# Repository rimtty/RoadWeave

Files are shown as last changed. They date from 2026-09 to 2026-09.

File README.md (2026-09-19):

# RoadWeave

RoadWeave は、インターネットや携帯回線がない場所でも、ツーリング中の車両どうしでグループ音声と位置情報を共有する小型端末の研究開発プロジェクトです。

製品の核は **ESP32-S3 + Wi-Fi HaLow + IP-PTT** です。最初は2台のブレッドボードで低遅延の半二重音声を成立させ、そこから「オフラインのDiscord風ボイスルーム」、指定相手へのPTT、個別ミュート・音量、音声記録、GPS隊列表示へ段階的に育てます。

## 開発ライン

| ライン | 無線モジュール | 位置づけ |
|---|---|---|
| P0 reference | Seeed Studio Wio-WM6180 / FGH100M-H / MM6108 | XIAO ESP32S3へ直接挿し、公式board profileでhost/networkを先行検証する。量産BOMの決定ではない |
| Main | Heltec HT-HC01 V2 / MM6108 / 27 dBm級 | 機能・距離・電力の主開発。日本国内では適合確認前に通常の空中線送信を行わず、シールド環境・導通試験または適法な地域で評価する |
| Japan side line | FGH100M-J / MegaChips MRF61_A | 日本向け製品化を並走検討。認証、antenna、国内band、出力、Duty、供給条件を実機・一次資料で検証する |

最初にWM6180を使うのは、はんだ付けや自作carrierなしで、公式pin/BCF設定からsoftwareを検証できるためです。WM6180での成功はHC01 V2固有の電源・PA・RF性能を証明しません。HC01 V2を主系にするのは、PA/LNAを含むRF性能と入手性を評価するためで、日本で販売・使用する製品がHC01 V2のまま成立する、という意味ではありません。

## 最初の成功条件

2台のブレッドボードで次を再現できたら P0 完了です。

1. Node AでPTTを押す
2. 16 kHz mono音声をIMA-ADPCM化してUDP送信する
3. Node Bのスピーカーから100〜150 ms以内を目標に再生する
4. パケット損失、遅延、消費電力、RF airtimeを記録する

LCD、GPS、Opus、録音、メッシュはP0の完了条件に含めません。

## リポジトリ構成

```text
RoadWeave/
├── design/                  UI/UXデザイン検討
│   └── web-poc/            Circle・Pulse・CompassのWeb PoC
├── docs/                    設計判断、仕様、試験計画
│   └── decisions/          変更理由を残すADR
├── firmware/                ESP-IDFアプリケーション
│   ├── components/         rwp、audio_pipeline、opus
│   ├── experiments/        opus_bench、audio_bench、voice_udp
│   ├── sim/                host simulator（floor + voice over lossy channel）
│   └── boards/             module 別の profile / BCF
├── hardware/
│   └── kicad/              回路図・PCB・製造出力（今後追加）
└── tools/                   rwp_peer.py（Mac 側 echo / record / send）
```

## 設計文書

- [製品定義 v2（最終形モックの吟味）](docs/product-definition-v2.md)
- [事業性の再検討 v2](docs/business-case.md)
- [アーキテクチャ](docs/architecture.md)
- [BOM v2・100/1,000/10,000台コスト](docs/bom.md)
- [電力・バッテリー予算](docs/power-budget.md)
- [ESP32-S3 GPIO割り当て案](docs/gpio-allocation.md)
- [macOS / Windows / Linux CI開発環境](docs/development-environment.md)
- [KiCad回路図ブロック案](docs/kicad-schematic-plan.md)
- [PoCロードマップ](docs/poc-roadmap.md)
- [実行スケジュール](docs/schedule.md)
- [音声ネットワーク設計](docs/voice-networking.md)
- [GPS隊列・breadcrumb・PMTiles構想](docs/gps-and-maps.md)
- [XIAO + WM6180初回起動手順](docs/bringup/xiao-wm6180-first-boot.md)
- [P0-A software検証記録](docs/bringup/p0-a-software-validation.md)
- [920 MHz 帯の国内制度](docs/regulatory-920mhz-japan.md)
- [ディスプレイ選定](docs/display-selection.md)
- [Audio bench notes](docs/bringup/audio-bench-notes.md)
- [Opus benchmark 2026-09-05](docs/bringup/opus-bench-2026-09-05.md)
- [voice_udp 計測 2026-09-06](docs/bringup/voice-udp-2026-09-06.md)
- [消費電力の計測手順](docs/bringup/power-measurement-plan.md)
- [ADR-0001: 開発ラインと段階戦略](docs/decisions/0001-development-lines.md)
- [ADR-0002: WM6180をP0 reference platformにする](docs/decisions/0002-wm6180-reference-platform.md)
- [ADR-0003: HC01P V2 + HATをbreakoutにする（Proposed）](docs/decisions/0003-hc01p-hat-breakout-and-linux-bridge.md)

## UIデザインの検討

[design/web-poc](design/web-poc/README.md) で、Circle・Pulse・Compassの3案を操作して比較できます。起動手順と検証範囲は各READMEを参照してください。音声・位置・接続は仮データです。

## 現時点の重要ゲート

- Morse MicroのESP-IDF向けHaLowコンポーネントはプレリリース。P0-AはESP-IDF `v5.4.4`とcomponent `2.11.2-esp32-2`を固定し、XIAO + WM6180公式profileから検証する。
- 購入したWM6180は902–928 MHz系。日本国内で通常の空中線送信をせず、RF fixtureと適法な試験条件を先に確定する。
- **HC01 V2用BCFとファームウェアの組み合わせを実機確認するまで、製品主系の採用は確定しない**。
- HC01 V2は3.3 V系とPA用5 V系を持つ。27 dBm・100% TXでは5 V側が最大約400 mA級になるため、平均値だけで電源を設計しない。
- 日本向けはMRF61_Aを別BOM・別RF試験として維持する。モジュールの技適だけで、アンテナ条件、最終製品のEMC・安全・表示など全要件が自動的に完了するわけではない。
- 地図PoCは地図データなしの隊列・Radar・breadcrumbから始める。PMTilesはmicroSDと描画負荷の実測後に判断する。

## 主要な一次資料

- [Heltec HT-HC01 V2 product page](https://heltec.org/project/ht-hc01-v2-wifi-halow-module/)
- [Heltec HT-HC01 V2 datasheet Rev.2.0](https://resource.heltec.cn/download/HT-HC01_V2/Datasheet/HT-HC01_V2.pdf)
- [Morse Micro HaLow ESP-IDF component](https://components.espressif.com/components/morsemicro/halow)
- [ESP32-S3-WROOM-1 datasheet](https://www.espressif.com/sites/default/files/documentation/esp32-s3-wroom-1_wroom-1u_datasheet_en.pdf)
- [MegaChips MRF61_A product page](https://www.megachips.co.jp/product/modules/wifi-halow/rf-modules/)

## ステータス

2026-09-19時点: 3組のSPI診断に加え、両STAのDHCP通信と3台同時通信を確認しました。
software restart時の不具合を修正し、AP/STA再起動各3回・APサービス再開3回の自動復帰、1/2 MHz各3回の有限通信を実証しています。
追加負荷は両幅で約82 kbit/s、3台同時では両STAの交互再起動中も相手の通信が継続しました。最終状態は3台とも無線停止です。
ESP32内蔵Wi-Fiは使用していません。8時間運転、実電源断50回、電源計測、現物受入の未確認分が残り、P0-A全体は未完了です。
[当日実証結果](docs/bringup/p0-a-validation-report-2026-09-19.md)、[残課題](docs/bringup/p0-a-open-items-2026-09-19.md)、[計測器・電源治具の準備](docs/bringup/p0-a-equipment-followups-2026-09-19.md)を参照してください。

最大転送速度は、固定低負荷echoと分けて[UDP stream実測](docs/bringup/p0-a-throughput-report-2026-09-19.md)に記録しています。受信側goodput、損失、送信負荷への追随、60秒3反復の合格値と飽和時の観測値を区別しています。

以下は2026-09-06時点の履歴:

- XIAO ESP32S3 1 台目: Gate 1（USB/flash/PSRAM smoke）PASS。残り 2 台と Wio-WM6180 x3 は到着待ち。
- ESP-IDF v5.4.4 を恒久インストール（`~/esp/v5.4.4/esp-idf`）。porting assistant と Gate 4 用 example（softap / sta_connect / iperf）は XIAO profile でビルド済み。
- P0-B の部品を先行実装: RWP/0.1 + floor control（`components/rwp`）、IMA-ADPCM + jitter buffer（`components/audio_pipeline`）、host test と host simulator（`firmware/sim`）を CI で実行。
- Opus は XIAO 単体で実測済み（[結果](docs/bringup/opus-bench-2026-09-05.md)）。
- 音声パイプラインを内蔵 2.4 GHz Wi-Fi で Mac と往復する実験（`experiments/voice_udp`）を初回計測（[記録](docs/bringup/voice-udp-2026-09-06.md)、アンテナ未装着）。
- HC01P V2 の mini PCIe pin map と Heltec BCF を `firmware/boards/heltec_hc01p/` に配置。HAT 40 pin は実測待ち。

本文書の金額・電力・通信性能は、購入記録または実測値と明記したものを除き設計仮定である。

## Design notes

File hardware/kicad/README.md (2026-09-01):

# KiCad hardware

Rev.AのKiCad projectは、[schematic block plan](../../docs/kicad-schematic-plan.md)のreview後に作成する。

追加時に必要なもの:

- `.kicad_pro`, hierarchical `.kicad_sch`, `.kicad_pcb`
- custom symbol/footprintのsourceとlicense
- HC01 V2公式footprint/reference designとの照合記録
- stack-upと50 ohm impedance条件
- ERC/DRC report、schematic PDF、assembly drawing
- HC01 V2 mainとMRF61_A Japan variantの差分表

生成物やbackupは`.gitignore`に従い、release用fabrication outputだけをtagまたはrelease artifactとして保存する。

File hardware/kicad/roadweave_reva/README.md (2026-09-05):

# roadweave_reva (KiCad 8 project skeleton)

`docs/kicad-schematic-plan.md` の階層構成を KiCad 8 のファイルとして起こした **骨組みだけ**のプロジェクト（2026-09-06、スクリプト生成）。
root に 8 枚の階層シートを置き、各シートは空。回路は入っていない。

- KiCad 10.0.6 の `kicad-cli` で ERC（違反 0、9 シート認識）と PDF 書き出しを確認済み（2026-09-06）。GUI で開いて保存すると
  KiCad 10 形式に書き換わるが問題ない。
- 回路を書き始める前提: HAT 40 pin の実測、電源 rail review（`docs/power-budget.md` §5）、HC01 V2 の reference design 照合。
- net 名は `docs/kicad-schematic-plan.md` §2 のとおりに付ける。

生成スクリプトは残していない（1 回限り）。バックアップ（`*-backups/`, `*.kicad_sch-bak`）は `.gitignore` 済み。

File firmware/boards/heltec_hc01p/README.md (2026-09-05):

# Heltec HC01P (V2) board files

取得日: 2026-09-05、出典: Heltec resource center。

| File | Source | SHA-256 |
|---|---|---|
| `bcf_HC0P.bin` (1,150 B, RISC-V ELF) | https://resource.heltec.cn/download/HT-HC01P/BCF/driver_1_15_3/bcf_HC0P.bin | `57c50cb2c1d51187667677b392684285c616ddbf3fe262c3aeece342f446773e` |
| `hc01p_pin_map.jpg` | https://resource.heltec.cn/download/HT-HC01P/Pin_Map/hc01p_pin_map.jpg | `2fbcd285b229137d56ad2b377bdc764d7ad93718d2e350b3c96c2cd4927ffbec` |
| `sdkconfig.defaults.seeed_xiao_esp32s3-heltec_hc01p_v2` | this repo (draft) | - |

BCF は Heltec 配布物であり license は未確認。再配布せず、必要なら上記 URL から再取得する。
Beyondlogic の記事では V1 用 `bcf_HC01P.bin` と V2 用 `bcf_HC01P-V2.bin` が別とされるが、resource center には
`bcf_HC0P.bin` 1 本しかない。**V2 用 BCF は Heltec に確認する**（Issue #2 / A-01）。

## HC01P mini PCIe pin map（pin_map.jpg より、host に必要な信号だけ）

| mini PCIe pin | Signal | Morse component Kconfig |
|---:|---|---|
| 1 | SPI_CS / SDIO_DATA3 | `CONFIG_MM_SPI_CS` |
| 2 | SPI_MOSI / SDIO_CMD | `CONFIG_MM_SPI_MOSI` |
| 3 | SPI_MISO / SDIO_DATA0 | `CONFIG_MM_SPI_MISO` |
| 4 | SPI_CLK / SDIO_CLK | `CONFIG_MM_SPI_SCK` |
| 48 | SDIO_DATA1 / SPI_INT | `CONFIG_MM_SPI_IRQ` |
| 10 | WAKEUP_IN | `CONFIG_MM_WAKE` |
| 11 | BUSY | `CONFIG_MM_BUSY` |
| 42 | RESET_N | `CONFIG_MM_RESET_N` |
| 6, 7, 27, 41, 52 | 3V3 | HAT 側で供給 |
| 5, 8, 9, 12, 13, 16, 19, 22, 28, 33, 36, 40, 44, 51 | GND | 共通 GND |

SPI mode に必要な 8 信号はすべて edge に出ている。UART/JTAG は出ていない。

## HT-HC01P HAT 40 pin header の対応（要実測）

Web 上の一次資料では 40 pin header の割り当てを確定できなかった（Heltec の Schematic_diagram は空、
「Morse Micro MMECH06 と同じ GPIO 割り当て」という記述のみ）。HAT が手元にあるので、**mini PCIe socket の
各 pin から 40 pin header へテスターの導通で当たる**のが最短で確実。

手順（無通電、module を抜いた状態）:

1. mini PCIe socket の pin 番号を確認する（奇数 pin は基板上面側、偶数 pin は下面側。pin 1 は切り欠きから遠い端）。
2. 上表の 8 信号 + 3V3 について、socket pin と 40 pin header の各 pin の導通を調べ、下表を埋める。
3. 期待値: SDIO 系は Raspberry Pi の SDIO alt 機能（BCM GPIO22=CLK, 23=CMD, 24=DAT0, 25=DAT1, 26=DAT2, 27=DAT3）
   = header pin 15, 16, 18, 22, 37, 13。RESET_N / WAKE / BUSY は別の GPIO。
4. 3V3 が header の 3V3（pin 1/17）直結か、HAT 上のレギュレータ経由（5V pin 2/4 から）かも確認する。

| Signal | mini PCIe pin | HAT header pin | RPi BCM GPIO | XIAO GPIO（profile） |
|---|---:|---:|---:|---:|
| SPI_CLK | 4 |  |  | 7 |
| SPI_MOSI | 2 |  |  | 9 |
| SPI_MISO | 3 |  |  | 8 |
| SPI_CS | 1 |  |  | 4 |
| SPI_INT | 48 |  |  | 3 |
| BUSY | 11 |  |  | 5 |
| RESET_N | 42 |  |  | 1 |
| WAKEUP_IN | 10 |  |  | 2 |
| 3V3 | 6/7/27/41/52 |  |  | - |

埋まったら `docs/gpio-allocation.md` の HC01 節へ転記する。

## 配線上の注意

- HaLow SPI は jumper wire なら 4 MHz 程度から始め、安定したら上げる（Morse community の実績: jumper 4 MHz、はんだ 40 MHz）。
- RESET_N は driver が能動的に driving する必要がある。pull-up 任せにしない。
- HC01P V2 は on-card で 5 V（FEM）を昇圧するため、HAT への 3V3 供給能力に余裕を持たせる。XIAO の 3V3 pin ではなく
  5 V → HAT のレギュレータ、または別電源から給電する。
- WM6180 と HC01P は同時に XIAO へ載せない（同じ GPIO を使う）。

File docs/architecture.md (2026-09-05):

# アーキテクチャ概要

更新日: 2026-09-02

## 1. 目的

RoadWeaveは車列向けのローカルIPネットワーク端末である。一般的なトランシーバーの置き換えだけでなく、同じHaLowリンク上に音声、発話者ID、GPS、車速、方位、接続状態を載せる。

設計目標:

- 携帯回線・クラウド不要
- P0は2台、製品は通常6〜8台（v2: 最低6人で1グループ）、設計上限は16台
- 半二重PTTのend-to-end音声遅延: 100〜150 ms以内
- 標準3000 mAh 1S LiPoで通常ツーリング15時間をストレッチ目標、12時間を最低設計目標
- 車載外部アンテナとハンディ運用の両方を許容
- 音声と位置情報はネットワーク断から自動復帰
- 日本向けRFはMRF61_Aラインで別途成立性を検証

## 2. 論理構成

```text
                         920/915 MHz Wi-Fi HaLow
                    ┌────────────────────────────┐
                    │ AP/STA group, WPA3-SAE     │
                    └──────────────┬─────────────┘
                                   │ SPI + IRQ/WAKE/BUSY
┌─────────────── RoadWeave node ───┴──────────────────────────┐
│ ESP32-S3-WROOM-1-N16R8                                     │
│                                                            │
│  audio capture -> codec -> UDP voice -> jitter buffer       │
│  group/floor control -> peer policy -> local mixer          │
│  GNSS -> position broadcast -> convoy/radar/breadcrumb UI   │
│  event log -> future recorder/storage abstraction           │
│                                                            │
│ I2S mic   I2S amp   1.47in IPS   GNSS   keys   microSD pad  │
└──────────────┬──────────────────────────────────────────────┘
               │
       USB-C / 1S LiPo / 3.3 V buck / 5 V boost
```

## 3. ハードウェア基準構成

| ブロック | 方針 | 理由 |
|---|---|---|
| P0 reference | XIAO ESP32S3 + Wio-WM6180 | header直結と公式board profileで、host/network softwareを最短で検証 |
| MCU | ESP32-S3-WROOM-1-N16R8 | PSRAMを音声buffer、地図cache、UIに使い、16 MB flashにHaLow FW/BCFとOTA余地を確保 |
| HaLow main | HT-HC01 V2、SPI host | 27 dBm級PA/LNA内蔵。ESP32向け公式コンポーネントのSPI構成と合わせる |
| HaLow Japan | MRF61_A（製品主構成、v2） | 技適済み 13 dBm。920.5〜923.5 MHz を factory lock（regulatory-920mhz-japan.md） |
| Mic | 16 kHz対応I2S MEMS（T5848級） | ADC/アナログプリアンプを避ける |
| Speaker | MAX98357A級 + 4 ohm 3 W | I2S DAC/Class-D一体、PoC入手性 |
| Display | 2.8 inch IPS 240x320 + 静電容量タッチ（v2） | 隊列・レーダー・ルートを走行中に一目で読む。タッチは停車時の設定用 |
| GNSS | UART、1 Hz以上、PPS pad | まず位置・速度・方位。型番はPoC比較後に固定 |
| Storage | Rev.AにmicroSD socket/pad、P0はDNP可 | 録音とPMTilesを基板改版なしで試せる余地 |
| Battery | protected 1S LiPo 3000 mAh | 薄型筐体と一日運用のバランス |

## 4. ソフトウェア境界

| コンポーネント | 責務 | 他層への依存 |
|---|---|---|
| `halow_port` | MM6108起動、BCF/FW、AP/STA、RSSI、power-save | Morse Micro ESP-IDF component |
| `voice_transport` | voice/control UDP、sequence、loss統計 | socketsのみ |
| `audio_pipeline` | I2S、codec、jitter buffer、limiter | network非依存 |
| `group_service` | peer表、floor、target、mute/gain | transport abstraction |
| `position_service` | GNSS、位置broadcast、clock quality | UART/GNSS abstraction |
| `route_model` | ENU座標、breadcrumb、route projection | map renderer非依存 |
| `ui` | active speaker、group、convoy/radar/route | read-only state models |
| `storage` | settings、logs、将来のrecord/PMTiles | flash/microSD abstraction |

音声、位置、UIをHaLowドライバから直接呼ばない。WM6180 referenceからHC01 V2、FGH100M-J、MRF61_Aへ切り替える際に、`halow_port`とboard/RF設定以外をできるだけ共通化する。

## 5. ネットワーク形態

P0/P1は、1台をGroup Coordinator兼HaLow AP、他をSTAとするstarを採用する。ルーターもインターネットも不要で、APはIP接続点にすぎない。Coordinator故障時の再選出はP3以降に追加する。

```text
           CAR-02
              |
CAR-03 --- CAR-01(AP) --- CAR-04
              |
           CAR-05
```

最初から802.11sやMANETを必須にしない。車列では中継が価値を持つが、音声・電力・RFの基礎測定より先にmeshの不確実性を持ち込まない。

## 6. データフロー

### TX

`PTT -> floor request -> mic I2S -> high-pass/AGC -> codec -> voice packet -> UDP -> HaLow`

### RX

`HaLow -> UDP -> peer policy -> jitter buffer -> decode -> gain/mute -> limiter -> I2S amp`

### Position

`GNSS -> fix validation -> 1 Hz beacon -> peer table -> local ENU -> convoy/radar/route UI`

## 7. 信頼性と安全側の挙動

- PTTを離したらローカルTXを即停止し、PTT_END欠落はlease timeoutで回収する。
- link断時に音量最大・speaker pop・PTT stuckを起こさない。
- LiPo低電圧時はLCD輝度とTX出力を段階制限し、突然電断する前にログを閉じる。
- GNSS fixが古いpeerは距離を確定表示せず、ageを示す。
- 運転中UIは一目で読める表示を優先し、設定操作を制限する。
- 録音は初期状態OFF。録音中は常時表示し、地域の会話録音ルールと参加者同意を製品要件にする。

## 8. 未決事項とゲート

| ID | 未決事項 | 解消条件 |
|---|---|---|
| A-00 | WM6180 referenceの再現性 | XIAO 3台smoke、3組porting assistant、2-node AP/STA/UDP soak |
| A-01 | HC01 V2に対応するBCF/FWの正式な組み合わせ | porting assistant全項目PASS、AP/STA両方の連続試験 |
| A-02 | ESP32-S3でOpusを何stream処理できるか | 8/12/16 kbps、1〜2同時speaker、CPU/RAM/温度実測 |
| A-03 | HC01とMRF61の共通carrier PCB可否 | pinout、電源、keepout、認証アンテナ条件比較 |
| A-04 | 通常group上限 | 8/16台でpacket loss、floor時間、GPS beacon airtime測定 |
| A-05 | PMTiles方式 | raster/vector双方のmicroSD seek、decode、frame time測定 |

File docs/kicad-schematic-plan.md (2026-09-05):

# KiCad回路図ブロック案

更新日: 2026-09-02  
目標: Rev.A回路図を階層sheetへ落とす前のnet・責務分割

## 1. sheet構成

```text
00_top.kicad_sch
├── 01_power_usb_battery.kicad_sch
├── 02_esp32s3.kicad_sch
├── 03_halow_hc01.kicad_sch
├── 04_audio.kicad_sch
├── 05_display_ui.kicad_sch
├── 06_gnss.kicad_sch
├── 07_storage_expansion.kicad_sch
└── 08_connectors_test.kicad_sch
```

HC01 V2とMRF61_Aを同じsheetのvariant stuffingに押し込まない。`03_halow_hc01`を主schematicとし、MRF61_Aは別variant sheet/別board revisionで比較する。共通carrierが実証できた場合にだけ統合する。

## 2. 00_top

階層sheet間の信号と電源railだけを置く。

主要net:

```text
VBUS_5V, VBAT_RAW, SYS_BAT
SYS_3V3, HC01_3V3, HC01_5V0, AUDIO_5V0
HC01_SPI_{SCK,MOSI,MISO,CS_N,IRQ}, HC01_{RESET_N,WAKE,BUSY}
AUDIO_{BCLK,WS,MIC_DATA,SPK_DATA,AMP_SD_N}
AUX_SPI_{SCK,MOSI,MISO}, LCD_{CS_N,DC,BL_PWM}, SD_CS_N
GNSS_{RX,TX,PPS}, PTT_N, KEY_VOL_UP_N, KEY_VOL_DOWN_N
USB_D_P, USB_D_N
```

## 3. 01_power_usb_battery

含める回路:

- USB-C 5 V sink、CC resistors、ESD、fuse/polyfuse
- charger + power-path、1S LiPo connector、NTC
- battery protectorはprotected cell任せにせず二重化方針を明記
- 3.3 V buck、5 V boost、load switch
- fuel gaugeまたはbattery ADC option
- reverse current、USB挿抜、brownout対策
- railごとの0 ohm/current-shunt footprintとtest point

設計review:

- HC01 27 dBm TX load stepで5 Vが規定内
- 5 V boost起動中はAMP_SD_Nをlow、HC01 RESET_Nをlow
- USB給電中の充電発熱と同時TXのthermal worst case
- battery connector逆挿し防止、cell short対策

## 4. 02_esp32s3

- ESP32-S3-WROOM-1-N16R8
- EN RC/reset button、BOOT button
- native USB D+/D-、ESD、series resistorsはEspressif guideline準拠
- antenna keepout（PCB antenna版を使う場合）
- GPIO labelは[GPIO allocation](gpio-allocation.md)と一致させる
- spare test pads、factory programming pads

MCUの2.4 GHz antennaとHaLow RF/coax、5 V boost switching nodeを物理的に離す。

## 5. 03_halow_hc01

- HT-HC01 V2 footprint、SPI、IRQ、RESET_N、WAKE、BUSY
- VBAT/VDD_IO 3.3 V、VDD_FEM 5 Vのlocal decoupling
- JTAG/unused GPIO pulldown footprints
- SPI series damping resistor footprints、CS/RESET default state
- 50 ohm controlled-impedance traceを最短でU.FLへ
- π matching footprintはreference designに従い、勝手に値を固定しない
- module/antenna keepout、shield can option
- conducted test用U.FLまたはswitchable RF test connector

Heltecの[公式SPI reference design](https://resource.heltec.cn/download/HT-HC01_V2/Reference_design/HT-HC01_V2_SPI.PDF)とdatasheetをERC前に再確認する。

## 6. 04_audio

- I2S MEMS mic、clock/data、L/R select、local low-noise decoupling
- MAX98357A級amp、gain strap、SD/mute、output filter/EMI parts
- 4 ohm speaker connector、ESD、short protection
- micとspeakerのacoustic separation、speaker chamberはmechanical要件へ渡す
- optional headset/line-outはP0 DNP

firmwareだけに依存せず、ESP reset時もampをmuteするpulldownを置く。class-D traceをGNSS/RF/micから離す。

## 7. 05_display_ui

- 2.8 in ILI9341 / ST7789 系 IPS 240×320、FPC connector（v2: 製品定義 v2 で 1.47 in から変更）
- AUX SPI SCK/MOSI、LCD_CS_N、LCD_DC、LCD_RESET
- backlight LED boost driver + PWM（25 kHz）、current limit
- 静電容量タッチ FT6336: I2C（TOUCH_SDA/SCL）、TOUCH_INT_N、TOUCH_RST
- PTT、VOL+、VOL-、power key
- night brightnessとglove operationをmechanical仕様に反映

## 8. 06_gnss

- UART GNSS module + PPS test pad
- antennaタイプ（chip/patch/U.FL）はDNP variant
- backup supply/supercap option
- ESDとantenna keepout
- class-D、boost、HaLow TXからのdesense測定point

## 9. 07_storage_expansion

- microSD socket、card detect、ESD、series resistors
- AUX SPI共用、独立SD_CS_N
- P0はDNP可能だがroutingとfootprintは残す
- 3.3 V peak currentとhot insertionを考慮
- 将来のrecording/PMTiles用。Rev.A機能のboot依存にしない

## 10. 08_connectors_test

- factory pogo: 5 V、3.3 V、GND、EN、BOOT、USB D+/D-またはUART
- rail current links
- audio loopback/test input、speaker test pads
- GNSS UART/PPS
- HC01 SPI/IRQ/RESET/WAKE/BUSY
- RF conducted test connector
- board ID/revision resistor

## 11. KiCad milestone

1. Symbols/footprints sourceとlicenseを記録
2. top + power + MCU + HC01のみでERC
3. reference designとのpin-by-pin checklist
4. audio/display/GNSS/storage追加
5. stack-up/impedanceをfabricatorに確認してPCB開始
6. schematic PDF、BOM、netlist、ERC logをdesign review tagへ保存

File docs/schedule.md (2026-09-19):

# RoadWeave 実行スケジュール

更新日: 2026-09-19（最新到達点を追記。下記の日程・過去在庫は未再調整）

## 2026-09-19の到達点

XIAO + WM6180の3組でSPI診断、両STAのDHCP通信、3台同時UDP通信を確認した。
software restartで見つかったGPIO割り込みwatchdogを修正し、AP/STA再起動各3回・APサービス再開3回の復帰を実証した。
3台同時baselineと両STA交互再起動時の相手の継続、両幅の約82 kbit/s有限負荷も確認し、最後に全3台の無線を停止した。
1/2 MHzを同一修正版で各3回測定し全回PASS。内蔵Wi-Fiは使っていない。測定範囲と限界は当日レポートを参照。
8時間soakは今回対象外。実電源断50回は電源制御と手作業を実施できないため[Issue #27](https://github.com/rimtty/RoadWeave/issues/27)、
電流・rail電圧は計測器購入が必要なため[Issue #28](https://github.com/rimtty/RoadWeave/issues/28)に残す。
現物受入の未確認分もあり、P0-A全体は未完了。3台同時通信は追加試験として区別する。

- [当日実証結果](bringup/p0-a-validation-report-2026-09-19.md)
- [UDP最大転送速度の実測](bringup/p0-a-throughput-report-2026-09-19.md)
- [計測器・電源治具の準備](bringup/p0-a-equipment-followups-2026-09-19.md)
- [残課題・判定基準・次の実行順](bringup/p0-a-open-items-2026-09-19.md)

Issue/Projectの進捗・日程更新は別途必要。以下の計画日付を現在の完了状況として読まない。

到着日は物流で変動するため、日付だけでなくgate完了を次工程の開始条件にする。GitHub Project #2のStart date、Target date、Iterationをsource of truthとして同期する。

## 現在のP0-A

| 期間 | Task | Gate / 成果物 | GitHub |
|---|---|---|---|
| 2026-09-02〜09-03 | firmware/toolchain準備 | ESP-IDF 5.4.4固定、XIAO smoke build、初回起動手順 | 新規P0-A prep task |
| 2026-09-03〜09-08 | 到着・外観・XIAO単体試験 | 3台すべてUSB/flash/PSRAM PASS | Issue #1 |
| 2026-09-04〜09-11 | WM6180 stack / porting assistant | 3組すべて公式profileで全項目PASS | Issue #2 |
| 2026-09-10〜09-18 | AP/STA・UDP・復帰 | 2 node接続、8時間soak、再起動復帰 | Issue #3 |

物流が遅れた場合はIssue #1〜#3を同じ日数だけslideし、RF安全gateや3台全数確認を省略して取り戻さない。

## 2026-09-05時点の状況

| 項目 | 状態 |
|---|---|
| XIAO ESP32S3 | 1台到着・Gate 1 PASS（[log](bringup/logs/2026-09-05-p0a-gate1-node1.md)）。残り2台は未実施 |
| Wio-WM6180 x3 | 到着待ち |
| HC01P V2 + HT-HC01P HAT x3 | 手元にあり。位置付けは[ADR-0003](decisions/0003-hc01p-hat-breakout-and-linux-bridge.md)（Proposed） |
| SPH0645 x3 | 手元にあり。amp/speaker/PTTはIssue #18で到着待ち |
| RF fixture | **未発注**。Gate 3は50 ohm終端のみで可、Gate 4はattenuator chainが必要 |
| ESP-IDF v5.4.4 | `/tmp`配下の一時installだったため`~/esp/v5.4.4/esp-idf`へ移設中（[開発環境](development-environment.md)） |

Issue #2（target 09-11）はWM6180到着とRF fixture確保に依存するため、到着日確定後に同じ日数だけslideし、理由をIssue commentへ残す。

### 到着待ちの間に進める作業（hardware不要または手元部品で可能）

| # | 作業 | 状態（2026-09-05） |
|---|---|---|
| 1 | 残り2台のXIAO Gate 1（到着次第、各10分） | 待ち |
| 2 | RWP/0.1のserialize/parseとfloor state machineをhost unit test付きで実装（Issue #5前半） | **完了**: `firmware/components/rwp`、host test 176 checks PASS、CIにhost-tests job追加 |
| 3 | Opus encode/decodeのCPU/RAM benchmark（Issue #14前倒し） | **完了**: [結果](bringup/opus-bench-2026-09-05.md)。12 kbps/20 ms/c0で encode 18.7% + decode 4.3%（1 core比） |
| 4 | SPH0645のI2S capture確認（Issue #4前半） | **firmware完成・実配線待ち**: `firmware/experiments/audio_bench`。mic未接続でboot/I2S/meter動作を確認済み |
| 5 | I2S mic/amp loopbackとPTT hard mute（Issue #4後半） | **firmware完成・部品到着待ち**: 同上（loopback / test tone / PTT muteをKconfigで切替） |
| 6 | HT-HC01P HATの40 pin→SPI/BUSY/RESET_N/WAKE対応を確認し`gpio-allocation.md`へ追記 | **半分完了**: mini PCIe側はpin mapで確定、Heltec BCFとdraft profileを`firmware/boards/heltec_hc01p/`に配置。40 pin header側は回路図が公開されていないため**テスターで実測**（手順は同READMEに記載） |
| 7 | RF fixture発注: U.FL(MHF1)–SMA pigtail x3、SMA 50 ohm終端 x3、SMA 30 dB固定attenuator(2 W) x2、SMA F-F barrel x1 | 未発注 |
| 8 | IMA-ADPCM codecとjitter bufferをpure C + host testで実装（Issue #6の部品） | **完了**: `firmware/components/audio_pipeline`、host test 459 checks PASS |
| 10 | host simulator（coordinator + 2〜4 node、ロス/遅延/バースト注入） | **完了**: `firmware/sim`、6 シナリオ PASS、CI 実行。BUSY_WAIT 再要求の欠落を発見して修正 |
| 11 | 消費電力の計測手順 | **完了**: [手順](bringup/power-measurement-plan.md) |
| 12 | Opus を実パイプラインで計測 | **完了**: audio タスク CPU 21%、mouth-to-ear 84 ms（[記録](bringup/voice-udp-2026-09-06.md)） |
| 13 | 920 MHz 帯の送信時間制限の一次資料調査 | **完了**: 920.5〜923.5 MHz は総送信時間の制限なし（[まとめ](regulatory-920mhz-japan.md)、[RFQ 下書き](megachips-rfq-draft.md)） |
| 14 | 位置ビーコン（P3）の pure C 実装 | **完了**: `firmware/components/position`、host test 58 checks |
| 15 | Rev.A KiCad 骨組み | **完了**: `hardware/kicad/roadweave_reva`、kicad-cli 10.0.6 で ERC 0 / PDF 出力 OK |
| 17 | 製品定義 v2 / BOM v2 / 事業性の再検討（最終形モック基準） | **完了**: [product-definition-v2](product-definition-v2.md)、[bom](bom.md)、[business-case](business-case.md)。Issue #19〜#21 |
| 16 | 2.8 インチタッチディスプレイの選定と LVGL 先行実装 | **完了（ビルドのみ）**: [display-selection](display-selection.md)、`experiments/ui_lvgl`（ILI9341 + XPT2046 + LVGL 9、3 画面 + シミュレータ）。実機はディスプレイ到着後 |
| 9 | UDP音声パイプラインをXIAO内蔵Wi-FiでMacと往復（HaLow代役、Issue #6/#7の前倒し） | **計測済み（アンテナ未装着、ルーター直近）**: 安定 60 s で RTT median 8 ms、mouth-to-ear median 100 / p95 160 ms（jb 80 ms）。floor control + PLC 結線済み。[記録](bringup/voice-udp-2026-09-06.md) |

2〜5 は `feat/p0-prep-rwp-audio`（main へ merge 済み）、6・8・9 は `feat/p0-prep-2` の成果。

## P0-B以降

| 期間 | Phase | 主な成果 |
|---|---|---|
| 2026-09-15〜09-23 | P0-B audio local | I2S mic/amp loopback、hard mute、underrun測定 |
| 2026-09-15〜09-25 | P0-B protocol | RWP/0.1 packet、PTT lease、malformed/sequence test |
| 2026-09-22〜10-02 | P0-B 2-node voice | IMA-ADPCM/UDP、100〜150 ms目標 |
| 2026-09-29〜10-09 | P0-B measurement | latency/loss/airtime/power測定 |
| 2026-10-01〜10-30 | EVT readiness | 電源rail実証、Rev.A KiCad review |
| 2026-10-26〜11-27 | P1 group voice | 4-node coordinator、targeted PTT、mute/gain、UI |
| 2026-12-01〜2027-01-29 | P2 convoy/Japan line | GPS convoy/breadcrumb、MRF61_A/FGH100M-J比較 |
| 2027-01-18〜03-19 | Future product spikes | Opus、recording、PMTiles-from-microSD |

## 次の判断点

1. **XIAO Gate:** 3台とも8 MiB flash/PSRAMを認識するか
2. **WM6180 Gate:** 公式profileでSPI、chip ID、FW/BCF、BUSYが通るか
3. **Network Gate:** 2台でAP/STAとUDPが8時間安定するか
4. **Product-line Gate:** HC01 V2 carrierへ進むか、FGH100M-JまたはMRF61_Aを優先するか
5. **P0-B Gate:** audio部品を購入し、IP-PTT latency測定へ進むか

## スケジュール変更ルール

- hardware到着前にsoftware prepとtest templateは完了させる
- blockerはIssueへlogと写真を添付し、次taskを`In progress`へ移さない
- 期日変更時は理由をIssue commentへ1行で残す
- 規制/安全gateは日程都合で省略しない

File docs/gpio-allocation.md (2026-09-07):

# ESP32-S3 GPIO割り当て案

更新日: 2026-09-08

対象: ESP32-S3-WROOM-1-N16R8 + HC01 V2、Rev.A draft 0.1

## 1. 方針

- P0-AのXIAO ESP32S3 + Wio-WM6180では、このRev.A案を配線せず、Morse Micro公式board profileをそのまま使う。
- HC01 V2はESP-IDF向けMorse Micro componentに合わせ、SDIOではなくfull-duplex SPI + DMA + level interruptから開始する。
- GPIO26〜37はflash/Octal PSRAM競合を避け、使用しない。
- GPIO0/3/45/46はstrapping pinのため通常機能に割り当てない。
- GPIO19/20はnative USB D-/D+として確保する。
- JTAG既定pinをLCDに使う代わりに、debugはnative USB Serial/JTAGを基本とする。
- peripheral signalはGPIO matrixでroutingする。表の割り当ては回路図作成前にESP-IDF buildと実配線で検証する。

制約の根拠は[ESP32-S3 GPIO documentation](https://docs.espressif.com/projects/esp-idf/en/stable/esp32s3/api-reference/peripherals/gpio.html)と[ESP32-S3-WROOM-1 datasheet](https://www.espressif.com/sites/default/files/documentation/esp32-s3-wroom-1_wroom-1u_datasheet_en.pdf)。

## 1.1 P0-A reference profile

Morse Micro HaLow component `2.11.2-esp32-2`同梱の`sdkconfig.defaults.seeed_xiao_esp32s3-seeed_xiao_mm6108`をsource of truthにする。

| Signal | GPIO |
|---|---:|
| RESET_N | 1 |
| WAKE | 2 |
| SPI IRQ | 3 |
| SPI CS | 4 |
| BUSY | 5 |
| SPI SCK | 7 |
| SPI MISO | 8 |
| SPI MOSI | 9 |

この割り当てはWio-WM6180/XIAO header用であり、下記HC01 V2 Rev.A案へ転記しない。BCFは`bcf_fgh100mhaamd.bin`、chipはMM6108を指定する。

**Wio-WM6180のBUSY/WAKE制約（2026-09-08実機確認）:** 上表はソフトウェアprofileの割り当てであり、全信号の物理接続を意味しない。
[Seeed公式回路図](https://files.seeedstudio.com/wiki/wifi_halow/res/WI-FI_HALOW_FGH100M_EXT01_V30_SCH_20241107.pdf)では
BUSY経路のR17とWAKEUP_IN経路のR10はDNP（未実装）。今回の実機ではSPI 40 MHz、chip ID 0x0306の100回連続読み出し、bulk転送がPASSしたが、
MM6108側BUSY出力レジスタをHIGHにしてもESP32 GPIO5はLOWのままだった。
[Morse Microの説明](https://community.morsemicro.com/t/mm-iot-esp32-porting-assistant-error-seeed-xiao-halow/1011/2)もBUSY未配線を明記し、通信時の省電力無効化を案内している。
標準実装ではBUSY依存の省電力動作を前提にしない。詳細は[実機SPI診断記録](bringup/wm6180-spi-2026-09-08.md)。

## 2. 割り当て表

| GPIO | Net / function | Dir | Boot state / circuit note | Status |
|---:|---|---|---|---|
| 0 | BOOT | input | strapping、button to GND、通常機能禁止 | fixed |
| 1 | BAT_SENSE | analog in | divider + RC、ADC calibration要 | draft |
| 2 | CHG_STATUS | input | charger open-drain、pull-up | draft |
| 3 | reserved | - | strapping、test padのみ | fixed |
| 4 | PTT_N | input | active-low、external pull-up、debounce | draft |
| 5 | KEY_VOL_UP_N | input | active-low | draft |
| 6 | HC01_SPI_SCK | output | DMA SPI bus、series R footprint | draft |
| 7 | HC01_SPI_MOSI | output | HC01 pad 21 / SPI_MOSI | draft |
| 8 | HC01_SPI_MISO | input | HC01 pad 17 / SPI_MISO | draft |
| 9 | HC01_SPI_CS_N | output | HC01 pad 22 / SPI_CS | draft |
| 10 | HC01_SPI_IRQ | input | HC01 pad 16 / SPI_INT、level interrupt確認 | draft |
| 11 | HC01_RESET_N | output | HC01 pad 35、active-low | draft |
| 12 | HC01_WAKE | output | HC01 pad 36 | draft |
| 13 | HC01_BUSY | input | HC01 pad 34 / MM_GPIO_0 | draft |
| 14 | AUDIO_BCLK | output | mic/amp shared clock | draft |
| 15 | AUDIO_WS | output | 16 kHz mono、mic/amp shared | draft |
| 16 | MIC_DATA | input | I2S MEMS DOUT | draft |
| 17 | SPK_DATA | output | MAX98357A DIN | draft |
| 18 | AMP_SD_N | output | boot時mute、active-high enable | draft |
| 19 | USB_D_N | bidir | native USB | fixed |
| 20 | USB_D_P | bidir | native USB | fixed |
| 21 | KEY_VOL_DOWN_N | input | active-low | draft |
| 26〜37 | NC | - | module flash/PSRAM path回避 | fixed |
| 38 | AUX_SPI_SCK | output | LCD + future microSD shared bus | draft |
| 39 | AUX_SPI_MOSI | output | LCD + microSD | draft |
| 40 | AUX_SPI_MISO | input | microSD、LCDは未接続 | draft |
| 41 | LCD_CS_N | output | display chip select | draft |
| 42 | LCD_DC | output | display data/command | draft |
| 43 | GNSS_RX | input | UART1 RX。ROM UART0出力との実装影響を確認 | risk |
| 44 | GNSS_TX | output | UART1 TX。USB console使用、UART0 console無効化 | risk |
| 45 | reserved | - | strapping | fixed |
| 46 | reserved | - | strapping、input-only制約にも注意 | fixed |
| 47 | SD_CS_N | output | P0はDNP可、test pad | reserved |
| 48 | LCD_BL_PWM | output | external transistorでbacklight制御 | draft |

LCD resetはESP32 ENに直接結ばず、専用RC/supervisorまたはLCD power/reset回路で処理する。GNSS UARTの43/44はboot logとの競合をbenchで確認し、問題があればKEYまたはADC pinとの交換を行う。

## 2.1 HC01P V2 + HT-HC01P HAT（breadboard 段階）

mini PCIe 側の信号は [firmware/boards/heltec_hc01p/README.md](../firmware/boards/heltec_hc01p/README.md) で確定済み
（CS=1、MOSI=2、MISO=3、CLK=4、WAKE=10、BUSY=11、RESET_N=42、SPI_INT=48）。HAT の 40 pin header 側は実測で埋める。
XIAO 側は WM6180 公式 profile と同じ GPIO を使う draft profile `sdkconfig.defaults.seeed_xiao_esp32s3-heltec_hc01p_v2` を用意した。

## 2.2 v2: 2.8 インチ静電容量タッチ表示の追加 pin（Rev.A draft 0.2）

| GPIO | Net / function | 備考 |
|---:|---|---|
| 38/39 | AUX_SPI_SCK / MOSI | LCD + microSD 共用（変更なし） |
| 41 | LCD_CS_N | 変更なし |
| 42 | LCD_DC | 変更なし |
| 48 | LCD_BL_PWM | 25 kHz、boost driver の EN/PWM |
| 4 / 5（I2C） | TOUCH_SDA / TOUCH_SCL | 静電容量タッチ（FT6336）と将来のセンサで共用。PTT/VOL は別 GPIO へ移す |
| 21 | TOUCH_INT_N | KEY_VOL_DOWN から振り替え |
| 1 / 2 / 3（I2C 化で空く GPIO4/5 の代替） | PTT_N / KEY_VOL_UP_N / KEY_VOL_DOWN_N | BAT_SENSE は ADC 対応 GPIO へ再配置（要 review） |

表 §2 は v1 のまま。§2.2 の振り替えは KiCad 02/05 シート作成時に §2 へ統合する。

## 3. HC01 V2 module pad対応

| HC01 pad | Name | ESP32 GPIO / treatment |
|---:|---|---|
| 16 | MM_SDIO_D1 / SPI_INT | GPIO10 |
| 17 | MM_SDIO_D0 / SPI_MISO | GPIO8 |
| 18 | MM_SDIO_CLK / SPI_SCK | GPIO6 |
| 19 | MM_VDD_IO | 3V3、hostと同一rail |
| 21 | MM_SDIO_CMD / SPI_MOSI | GPIO7 |
| 22 | MM_SDIO_D3 / SPI_CS | GPIO9 |
| 25 | VBAT | HC01_3V3 |
| 32 | VDD_FEM | HC01_5V0 |
| 34 | MM_GPIO_0 / BUSY | GPIO13 |
| 35 | RESET_N | GPIO11 |
| 36 | WAKE | GPIO12 |
| 38 | ANT_1 | 50 ohm -> U.FL/SMA path |
| JTAG, unused GPIO | unused | datasheetに従い10 k pulldown、DNP optionを含めreference design確認 |

HC01 V2 pad定義と未使用pin処理は[公式datasheet](https://resource.heltec.cn/download/HT-HC01_V2/Datasheet/HT-HC01_V2.pdf)を回路図source of truthにする。

## 4. firmware config対応

Morse Micro componentで必要になる代表値:

```text
CONFIG_MM_SPI_SCK=6
CONFIG_MM_SPI_MOSI=7
CONFIG_MM_SPI_MISO=8
CONFIG_MM_SPI_CS=9
CONFIG_MM_SPI_IRQ=10
CONFIG_MM_RESET_N=11
CONFIG_MM_WAKE=12
CONFIG_MM_BUSY=13
CONFIG_MM_CHIP_MM6108=y
```

実際のKconfig symbol名とcomponent versionは導入時に固定し、BCF/FW versionも同じcommitに記録する。現行component情報は[Morse Micro HaLow for ESP-IDF](https://components.espressif.com/components/morsemicro/halow)を参照。

## 5. 回路図release前チェック

- [ ] N16R8 module variantの実pin availabilityをsymbol/footprintと照合
- [ ] PTT、key、ampがreset中に安全stateになる
- [ ] HC01 IRQが選択GPIOでlevel-triggered interruptとして動く
- [ ] HC01 SPIがfull-duplex DMAでporting assistantを通る
- [ ] USB download/consoleがLCD/GNSSなしでも使える
- [ ] LCD + microSD shared SPIでCSが同時assertされない
- [ ] ADC dividerがsleep currentと測定精度の両方を満たす
- [ ] strapping pinに外部回路が誤電圧を与えない

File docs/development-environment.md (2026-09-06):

# 開発環境と再現手順

更新日: 2026-09-06

## 方針

RoadWeaveの主開発環境はmacOSとする。実機のUSB接続、書き込み、monitorはmacOSで確認し、Windowsでも同じESP-IDF versionとコマンド列を再現できるようにする。どちらの環境でも`firmware/toolchain.lock`をversionのsource of truthとし、ESP-IDFは`v5.4.4`を使う。

macOSでは2026-09-02にHomebrewのCMake `4.4.3`とNinja `1.13.2`でESP32-S3 buildを確認済み。これは再現実績であり、Windowsへ同じhost tool versionを強制するものではない。WindowsではESP-IDF Tools Installerが管理する互換versionを使い、Linux CIでは公式ESP-IDF containerのtoolchainを使う。

WindowsではEspressifのWindows向けESP-IDF環境を使い、PowerShellから`idf.py`を実行する。ESP-IDFのexport済みターミナルで作業を始めること。WSLはLinux系の補助作業には使えるが、USB flashとmonitorの経路には使わない。WindowsのUSBドライバとCOM portを使うnative PowerShell手順を正とする。

公式Windows installerはPython、Git、cross compiler、CMake、Ninjaをまとめて導入する。install pathは空白・括弧を避け、ESP-IDFとtoolsのpathを90文字以内にする。

## macOS（主開発環境）

### install場所とPython version（2026-09-05追記）

- ESP-IDF本体は`~/esp/v5.4.4/esp-idf`、toolsは`~/.espressif`（`IDF_TOOLS_PATH`既定）に置く。`/tmp`配下はOS再起動で消えるため使わない。
- `export.sh`は`python3`のminor versionでvenv名（`idf5.4_py3.X_env`）を決める。Homebrew Pythonが更新されると既存venvが見つからず`export`が失敗するので、その場合は`./install.sh esp32s3`を再実行するか、`IDF_PYTHON_ENV_PATH`で既存venvを明示する。
- 毎回の手順:

```bash
source ~/esp/v5.4.4/esp-idf/export.sh
```

ESP-IDF `v5.4.4`をインストールしてexportしたターミナルで、リポジトリのルートから次を実行する。`/path/to/RoadWeave`は実際のcheckout pathに置き換える。

```bash
cd /path/to/RoadWeave/firmware
./scripts/check-toolchain.sh
idf.py set-target esp32s3
idf.py build
idf.py -p /dev/cu.usbmodemXXXX flash monitor
```

`/dev/cu.usbmodemXXXX`は接続したXIAO ESP32S3のport名に置き換える。接続前後の候補は次で確認できる。

```bash
ls /dev/cu.usbmodem*
```

## Windows（native PowerShell）

2026-09-06に現在のWindows機で導入・実機確認済み。[Windowsベンチ手順と結果](bringup/windows-bench-2026-09-06.md)を参照。
このPCではRepoルートから次で専用環境へ入れる（PowerShellのプロファイルやシステムPythonは変更しない）。

```powershell
Set-Location D:\RoadWeave
Set-ExecutionPolicy -Scope Process -ExecutionPolicy Bypass
. .\firmware\scripts\enter-idf.ps1
```

ESP-IDF本体は`D:\Espressif\esp-idf-v5.4.4`、toolsは`D:\Espressif\tools`。
`enter-idf.ps1`は専用Python環境を選び、公式`export.ps1`を実行してversionを確認する。
別の設置先では`-EspressifRoot`、`-IdfPath`、`-PythonEnvPath`を指定できる。
Windowsの`.py`関連付けが別Pythonを指していても、`idf.py`はESP-IDF用Pythonで実行される。

EspressifのWindows向けESP-IDF環境を起動し、ESP-IDF `v5.4.4`がexportされたPowerShellで、次を実行する。`C:\path\to\RoadWeave`は実際のcheckout pathに置き換える。

```powershell
Set-Location C:\path\to\RoadWeave\firmware
.\scripts\check-toolchain.ps1
idf.py set-target esp32s3
idf.py build
idf.py -p COM5 flash monitor
```

`COM5`は例であり、デバイスマネージャーの「ポート (COM と LPT)」に表示されるXIAO ESP32S3のCOM portへ置き換える。PowerShellの実行ポリシーでスクリプトが拒否される場合は、現在のPowerShellプロセスだけを対象にしてから再実行する。

```powershell
Set-ExecutionPolicy -Scope Process -ExecutionPolicy Bypass
.\scripts\check-toolchain.ps1
```

書き込み後にmonitorを終了する場合は、ESP-IDF monitorの通常の終了操作を使う。WSLへCOM portを転送して書き込む手順は、USBドライバ、port切断、monitorの再接続が環境依存になるため、この再現手順には含めない。

## Linux CI

GitHub Actionsでは、Linux runner上で公式の`espressif/esp-idf-ci-action@v1`を使い、`esp_idf_version: v5.4.4`、`target: esp32s3`、`path: firmware`を固定してbuildする。CIはLinux上のコンパイル再現性を確認するためのもので、実機へのflash、USB monitor、XIAOの8 MiB flash/PSRAM smoke testを代替しない。workflowは`.github/workflows/firmware.yml`にある。

Actionsの対象は次のとおり。ESP32、USB port、AP、SSID/passwordは不要。

- Host tests: RWP/floor、ADPCM/jitter、positionのC単体テスト（ASan/UBSan有効）、損失・遅延を模擬するhost simulator、Python peerのcodec/localhost UDP/WAVテスト。
- Compile only: `fetch-upstream.sh`でOpus v1.5.2を取得してから`idf.py build`。Opus sourceはGit管理外なのでfresh checkoutでは取得が必要。
- 実機専用のflash/monitor、Opus実測、I2S mic/amp、Wi-Fi/HaLow実測、Flash/PSRAMの動作確認はActionsでは実行せず、接続済みPCで実施する。

`firmware/**`・`tools/**`・workflowの変更で起動する。Markdownだけの手順・計測結果更新は起動対象外。
ホストコードは`-std=c11`でコンパイルするため、非標準の`M_PI`へ依存しない。

## version確認

macOSでは`./scripts/check-toolchain.sh`、Windowsでは`.\scripts\check-toolchain.ps1`を最初に実行する。両方のスクリプトが`toolchain.lock`の`ESP_IDF_VERSION`と`idf.py --version`を照合し、versionが異なる場合はbuildへ進まない。

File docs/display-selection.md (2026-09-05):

# ディスプレイ選定（タッチ付き 2.8 インチ）

更新日: 2026-09-06

## 決定（2026-09-06、製品定義 v2）

製品は **2.8 インチ IPS 240×320 + 静電容量タッチ（FT6336 系）** を採用。PoC は同じコントローラの抵抗膜タッチ品で進める。

## 要件

- 走行中の操作は物理 PTT と大ボタンが主。タッチは停車時の設定・グループ操作・地図の pan/zoom 用。
- 車内の直射日光下で読めること（IPS、輝度 300 cd/m² 以上が望ましい）。手袋・振動下では静電容量式が有利、抵抗膜式は手袋で使える。
- Rev.A PCB に載せる前提で、**同じコントローラ（ILI9341 / ST7789）で「ピンヘッダ付きモジュール（PoC）」と「FPC 直付け（PCB）」の両方が入手できる**こと。
- 1.47 インチ 172×320 の初期案は「隊列と発話者の表示」には足りるが、地図とタッチ操作には狭い。2.8 インチ 240×320 を第一候補にする。

## 候補

| 段階 | 候補 | 解像度 / IF | タッチ | 備考 |
|---|---|---|---|---|
| PoC（今すぐ） | 2.8" ILI9341 SPI モジュール（ピンヘッダ、XPT2046 抵抗膜タッチ付き、約 ¥900） | 240×320 / SPI 40 MHz | XPT2046（SPI、同一バス） | ESP-IDF に `esp_lcd_ili9341` と `esp_lcd_touch_xpt2046` あり。LVGL 検証に十分 |
| PoC 代替 | ESP32-2432S028（ESP32 + 2.8" ILI9341 + タッチ、約 ¥1,800） | 同上 | XPT2046 | ESP32 クラシック搭載で XIAO とは別 MCU。**UI だけ**を先に作る開発ボードとしては便利だが、製品コードの検証には使わない |
| Rev.A PCB | 2.8" IPS 240×320 ILI9341（SPI、FPC 18〜40 pin）+ 静電容量タッチ FT6336 / FT5x06（I2C） | SPI + I2C | 静電容量 | ドライバは `esp_lcd_touch_ft5x06`。コントローラが同じなので UI コードは PoC からそのまま |
| Rev.A 代替 | 2.8" ST7789V 240×320 | 同上 | 同上 | `esp_lcd_st7789`。ILI9341 と API 互換 |

選定の決め手は「日光下の輝度」と「FPC 品の入手性」なので、Rev.A 前に 2〜3 種を実物で比較する。
高輝度（500 cd/m² 級）品は同じ ILI9341 で存在するが単価が上がる。

## ピン予算（Rev.A、docs/gpio-allocation.md に反映予定）

- LCD SPI: SCK / MOSI（+ MISO は不要）、CS、DC、RESET、BL（PWM 20 kHz 以上）= 6 本
- タッチ: I2C SDA / SCL + INT = 3 本（抵抗膜 XPT2046 なら SPI 共用 + CS + IRQ）
- 1.47 インチ案から +3 本程度。ESP32-S3-WROOM では余裕がある。

## ソフト

- LVGL 9 + `esp_lvgl_port`（Espressif 公式 glue）。SPI 40 MHz、部分描画（1/10 画面のダブルバッファ）で 25〜30 fps。
- `firmware/experiments/ui_lvgl` に、隊列リスト / レーダー / 通話状態の 3 画面を **ディスプレイなしでもビルドできる形**で先行実装
  （データはシミュレーション）。ディスプレイ到着後は menuconfig でピンを合わせるだけ。
- 画面は core 1、音声と無線は core 0（architecture.md の方針）。

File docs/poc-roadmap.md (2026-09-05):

# PoCロードマップ

更新日: 2026-09-02

各phaseは機能一覧ではなく、次へ進むための測定gateを持つ。

## P0-A: HaLow host bring-up

構成: 3 x Seeed Studio XIAO ESP32S3 + 3 x Wio-WM6180、audioなし。2台をAP/STA、1台を交換診断・cross-checkに使う。

実装:

- ESP-IDF `v5.4.4`とMorse Micro component `2.11.2-esp32-2`を固定
- XIAO単体でUSB Serial/JTAG、8 MiB flash、8 MiB PSRAMを確認
- 公式`sdkconfig.defaults.seeed_xiao_esp32s3-seeed_xiao_mm6108` profileを使用
- WM6180/FGH100M-Hの`bcf_fgh100mhaamd.bin`とfirmware整合を確認
- 3組でporting assistant
- AP/STA、UDP echo、RSSI、再接続

Exit criteria:

- 3台すべてでXIAO単体smoke PASS
- 3組すべてでporting assistant全項目PASS
- 2台でcold boot 50回、driver初期化成功100%
- 8時間連続UDPでpanic/memory leakなし
- AP/STA両方の設定と復帰手順を再現可能
- WM6180のidle/RX/TX currentとRF test条件を記録

Safety gate: FGH100M-H/WM6180は902–928 MHz系のため、日本国内の通常空間へ送信しない。RF端子を開放したまま送信せず、conducted/shielded testまたは適法な地域・設備を使う。

Stop condition: 公式profileで3組のporting assistantを再現できない、RF試験方法を確保できない、またはBCF/FWのlicense/供給条件を確認できない場合はAP/STAへ進まず、Morse Micro/Seeedへ確認する。

### P0-Aから製品main lineへの移行

WM6180でhost/networkを成立させた後、HC01 V2 carrierで同じtest suiteを再実行する。HC01 V2の3.3 V/5 V rail、27 dBm PA、BCF/FW、antenna pathは別gateであり、WM6180のPASSを代用しない。日本向けはFGH100M-JとMRF61_Aを比較する。

## P0-B: 2-node breadboard IP-PTT

構成: 2 x ESP32-S3 + validated HaLow reference + I2S mic + I2S amp + speaker + wired PTT。最初はWM6180、製品main lineではHC01 V2へ同じvoice testを移植する。

実装:

- 16 kHz mono PCM
- IMA-ADPCM 64 kbps、20 ms packet
- UDP sequence、PTT_START/END、20〜40 ms jitter buffer
- TX中speaker hard mute

Exit criteria:

- quiet benchでend-to-end p95 <=150 ms
- 30分会話でPTT stuck 0、audio underrun <1/10 min
- 1/2 MHz、packet size、MCSごとのloss/airtime/power表
- 電源挿抜、packet loss、Node再起動から自動復帰

## P1: Group IP-PTT

- **6台**（製品定義 v2: 通常 6〜8 台）、Group ID/User ID、active speaker。追加ハードは Issue #20
- Coordinator AP + STA
- floor request/grant/lease、all-group PTT
- 2.8in タッチ表示（LVGL、`experiments/ui_lvgl`）に`RX: USER`、link、battery、convoy

Exit criteria:

- 6台で同時PTT競合を安全に解決（BUSY_WAIT、host simulator で先行検証済み）
- 4時間の移動/bench attenuation試験で制御state不整合なし
- group参加/離脱が音声streamを壊さない

## P2: Vehicle PoC

- 3000 mAh battery、power path、外部車載antenna
- 2台以上で高速/市街/峠を安全な同乗評価体制で測定
- noise対策、compressor/limiter、night UI
- 2 MHz normal / 1 MHz long-range比較

Exit criteria:

- typical profile 12時間以上
- 車両電源・battery双方でbrownoutなし
- route別RSSI/loss/latency/GPS log
- 操作が運転注意を不当に奪わないことを同乗者が評価

## P3: Convoy GPS

- 1 Hz position beacon、age/quality
- Convoy / heading-up Radar / breadcrumb Route
- route上distance projection
- 8台simulation + 4台実機

Exit criteria:

- 位置の古さを誤って現在位置として表示しない
- 8 node相当でvoice p95 latencyをP1比+20 ms以内に維持
- breadcrumb memoryが上限内で循環し、長時間断片化しない

## P4: Opusと個別制御

- Opus voice 12/16 kbps、complexity 0〜1（6 decode 実測: c0 36.6% / c3 60.1%）
- individual mute、gain、targeted PTT
- leader/subgroup/private target
- application protocol versioning

Exit criteria:

- 8台、1 active speakerでCPU/RAM/qualityを測定
- 2 simultaneous speakers を正式仕様に（無線帯域の上限。MCU は 6 decode 可）
- target外へprivate audio payloadを送らない設計をpacket captureで確認

## P5: Recording

- microSDへOpus frame + timestamp + sender ID + GPS event
- ring buffer、graceful close、recovery index
- visible REC indicator、参加者同意flow

Exit criteria:

- power cut後に直前file以外を失わない
- 8時間logの再生・sender filter・GPS同期
- recordingでvoice latency/lossが悪化しない

## P6: Japan line

- MRF61_A carrier/EVKで同じvoice/position protocol
- 国内channel、power、Duty、指定antenna条件
- 技適表示、最終製品要件、EMC/安全を専門家と確認

Exit criteria:

- HC01主系との差分BOM/firmware/test report
- 法令上許容される設定をfactory lockできる
- RF airtime実測が適用制限内

## P7: PMTiles from microSD

- 地域限定PMTiles archive
- local file range reader、tile cache
- raster方式とpreprocessed vector方式を比較
- OSM attribution表示/同梱

Exit criteria:

- pan/zoomではなく走行追従時のframe timeと消費電力を評価
- voice deadlineを阻害しないI/O priority
- SD抜去/破損時もconvoy/breadcrumbへ自動fallback

## Rev.A PCBへ進む条件

P0-B完了に加え、HC01 BCF/FW供給、電源peak、SPI signal integrity、audio noiseの4点が再現できること。LCDやGPSの完成を待つ必要はない。

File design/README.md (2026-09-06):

# RoadWeave UI/UXデザイン

- [web-poc](web-poc/README.md): Circle・Pulse・Compassの3案を比較するWeb PoC。参加・退出、PTT、音量・消音、位置表示を仮データで試せます。

リポジトリ直下から `cd design/web-poc` で移動し、`npm ci` と `npm run dev -- --host 127.0.0.1` で起動します。検証手順とLVGLへの移植方針はWeb PoCのREADMEを参照してください。

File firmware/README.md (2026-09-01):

# Firmware

ESP-IDF application root。最初のapplicationはSeeed Studio XIAO ESP32S3単体のUSB console、flash、PSRAMを確認する。WM6180/MM6108は初期化せず、HaLow送信を行わない。

## 固定version

- ESP-IDF: `v5.4.4`
- Morse Micro HaLow component: `2.11.2-esp32-2`（pre-release）
- 公式board profile: `sdkconfig.defaults.seeed_xiao_esp32s3-seeed_xiao_mm6108`

正確な値は[`toolchain.lock`](toolchain.lock)をsource of truthとする。Morse Micro componentはESP-IDF `>=5.4.4,<6.0`を要求するため、P0-A中は別versionへ暗黙に更新しない。

## XIAO単体smoke test

ESP-IDFをinstallして環境をexportした後:

```bash
cd firmware
./scripts/check-toolchain.sh
idf.py set-target esp32s3
idf.py build
idf.py -p /dev/cu.usbmodemXXXX flash monitor
```

macOSではport名を次で確認できる。

```bash
ls /dev/cu.usbmodem*
```

成功時はboot logに`P0A_XIAO_SMOKE=PASS`と`HALOW_TX=DISABLED`が表示される。期待値は8 MiB flashと8 MiB Octal PSRAM。USB-Cは電源、書き込み、USB Serial/JTAG consoleを兼ねる。

## WM6180 porting assistant

[`scripts/create-porting-assistant.sh`](scripts/create-porting-assistant.sh)は、固定versionの公式exampleを`firmware/porting_assistant/`へ生成する。このdirectoryは再生成物のためGit管理しない。

このexampleはMM6108 firmware/BCFをloadし、bus/chip/throughput/BUSYを試験する。**最初のXIAO単体smoke testでは実行しない。** RF端子を開放したまま通電・送信せず、[初回起動手順](../docs/bringup/xiao-wm6180-first-boot.md)のgateを満たしてから使う。

## 方針

- reference bring-upはXIAO ESP32S3 + Wio-WM6180を公式profileで行う
- HC01 V2は製品主開発ライン、FGH100M-JとMRF61_Aは日本適合候補として別gateを持つ
- secret、SSID passphrase、recording data、注文情報をrepositoryへcommitしない
- `dependencies.lock`は導入後にcommitし、managed component自体はcommitしない

## 想定component境界

```text
components/
  halow_port/
  audio_pipeline/
  voice_transport/
  group_service/
  position_service/
  route_model/
  ui/
  storage/
```

P0-AではXIAO単体smoke、公式`porting_assistant`、`sta_connect`、`softap`の順に独立して通す。applicationへの統合はその後。

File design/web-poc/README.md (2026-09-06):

# RoadWeave UI Lab

同じツーリングIP-PTT体験を、3つのデザインで比較するWeb PoC。音声、接続、参加者、位置はすべて仮データです。マイクや位置情報の権限は要求せず、実際の音声は送信しません。

## 3つの方向

| 方向 | 主画面 | デザインの狙い |
| --- | --- | --- |
| Circle  | 仲間と発話者 | 柔らかな色、アバター、穏やかな輪で声の存在を伝える |
| Pulse | 前後の距離 | 大きな数字、暗い背景、ライムのアクセントで瞬時に読み取る |
| Compass | 自分中心の相対位置 | 紺色のレーダーに仲間と発話状態を重ねる |

`#circle` / `#pulse` / `#compass` で各案へ直接移動できます。

## デザイン・スナップショット集

`/explore` に、60の異なる表現を操作して見比べるデモを追加しています。ホーム上部の「60のデザインを見る」からも移動できます。

01–12は人物・距離・レーダー・仮想地図・波形・モノクロ・隊列・高コントラスト・光・計器・タイル・無線機の各方向。13–16は黒地に白いドットと赤いアクセントを使った距離・音声・レーダー・計器一覧です。`/explore#dot-studies` でドット表現へ直接移動できます。

01–16で箱根・4人・AKIから受信中・前方120m・後方85m/240mのサンプルを共有します。地図と方位はレイアウト検討用の仮表示です。各カードに専用の操作デモがあり、01–03には既存の3案へ戻るリンクも残しています。ドット文字はSVGの円で描画し、外部フォントや画像に依存しません。

17–32は走行中の視認性を考えた追加案です。`/explore#driving-studies` から情報の優先順位と全16案を確認できます。17–20は発話者、21–24は前後の距離、25–28は待受・送信・切断・位置未更新、29–32は情報密度を減らしたドット表現。240×320の縦画面に比例して文字も拡大縮小します。設計根拠・サイズ・状態の意味・今後の評価は [driving-studies.md](driving-studies.md) にまとめています。

33–40はAMOLEDを想定したBlack Editionです。`/explore#amoled-studies` で直接移動できます。純黒 `#000000` の背景に、大きな名前・前後・距離・受信状態を表示。色面と発光する影を省き、白、青、紫、緑、琥珀、赤などの小面積のアクセントと情報配置の違いを比較します。全案が受信中のAKI・前方120mを示し、40は後方REN・85mも併記します。240×320の縦画面を論理基準とし、状態24px、主情報44–68px相当を目安に拡大縮小。図形のドット数字を使う39以外は通常の太い文字を採用しています。日光下での視認性・実消費電力は未測定で、AMOLEDへの実装や動作変更は含みません。

41–48はBlack EditionのPlay Seriesです。`/explore#pop-studies` で、黒にレモン・ライム・水色・ピンク・コーラル・ミント・紫を加えた8案を比較できます。モーターサイクル用UIの方向記号とアクセントカラーを参考に、縦画面の相対距離・発話者表示へ展開しました。41は距離を囲う弧、42は大きな前方記号、43は発話者カプセル、44は前後の二色表示、45は音声記号、46は四角いドット数字、47は声を囲む弧、48は二色のコーナー。全案で受信中AKI・前方120m、44は後方REN・85mも表示。音声を表す棒や弧は送受信に連動し、計測値や進捗を示すものではありません。背景は全案純黒、状態は24px、重要な名前や距離は主に44–72px相当、補助情報は14px以上の論理サイズを目安にしています。実機の視認性・消費電力は未測定です。

49–54はChroma / Curve Studiesです。`/explore#curve-studies` から確認できます。鮮やかな色、黒へつながる丸い切り欠き、S字の区切り、グラデーションの細い輪郭をUIの面・境界として使う6案です。49 Cobalt Cove、50 Mint Current、51 Fuchsia Dock、52 Citrus Nest、53 Prism Contour、54 Tidal Pair。名前と距離は単色の領域に大きく置き、同じ受信中AKI・前方120mを表示します。54は後方REN・85mも併記。240×320基準の操作デモで、写真・ノイズ背景・常時アニメーションは使用していません。色面の比率が高い案は省電力優先のBlack Editionと別に、実機の消費電力と日光下の見やすさを比較する対象です。

55–60はColor Identity Studiesの改訂版です。`/explore#color-identity-studies` に、人物の図形やアバターを外し、アシッドライム #c6ff00、ホットピンク #ff16a5、エレクトリックブルー #397dff、オレンジ #ff6b00 の色帯・色面で識別する6案を掲載しています。55 Acid Strip、56 Side Current、57 Hot Pink Dock、58 Two Lanes、59 Electric Cove、60 Quiet Line。強い色、純黒、大きな距離、曲面の境界、控えめな縁の光沢で構成。55/56/58はライム前方120m、57はピンク後方85m、59はブルー後方240m、60はライムの位置未更新。58はピンク後方85mも併記します。自分はオレンジで固定。受信・位置未更新は文字で明示します。実機の色割当や通信処理を実装したものではなく、240×320基準の操作デモです。

## 60案の操作デモと車列・GPS

一覧の「声・距離 / 車列・GPS」で全60案を一括比較できます。各カードの操作デモはその案の画面を拡大し、同じ状態のまま両画面を切り替えます。URLの例：

「1人で発話 / 2人で発話 / 3人で発話」で、全60案を同じ人数にまとめて切り替えられます。「初期状態」で各案の元の場面に戻ります。人数を選んでカードを開くと、その人数で操作を開始します。発話者の複数選択と距離を操作する対象の選択は、別々のボタンです。

- `/explore?demo=46` — Mint Pixelの操作デモ。
- `/explore?demo=46&screen=fleet` — 同じ案の車列・GPS画面。

操作できる項目は、仲間の同時発話（複数選択）、相対位置（−999〜999m）、走行の再生、送信先、参加・退出、通信接続、位置未更新、受信音量、ミュート、リセットです。PTTはマウス・タッチ・フォーカス中のSpace/Enterで長押し。自分を含め最大3人が同時に発話でき、受信中も260msの許可待ちを経て模擬送信します。3枠が使用中なら押したまま待機し、枠が空いたら許可待ちへ進みます。リリース、短押し、フォーカス喪失、ポインターキャンセル、画面切替、閉じる、切断、退出で送信・待機を解除します。本体のソフトウェアキーボードはありません。

2〜3人の発話時は各案の配色・曲線・ドット表現を引き継ぐ同時通話画面に切り替え、名前（55〜60は色名）・各人の距離・個別メーターを表示します。自分の送信も同じ画面で確認できます。車列画面は発話中の順位に下線を付け、フッターに発話人数を表示します。元のCircle / Pulse / Compassも同じ最大3人の方針で、仲間・ライド・レーダーの全画面に現在の話者を並べます。ミュートは受信音だけに作用し、使用中の発話枠は解放しません。IP音声ストリームの実際のデコード・ミキシングは今回のWeb PoCには含めていません。

車列・GPSは全60案に専用の配色・角・線・ドット設定を持ち、縦積み、地図優先、横分割、タイル、レーダーの配置を使い分けます。前から並ぶ4人の車列、自分の順位、各車への相対距離、地図マーカー、選択中の仲間の緯度経度を表示します。位置を変えると並び順とマーカーが更新され、GPSを拡大して確認できます。位置未更新や切断時は古い順位・距離・仲間のマーカーを表示しません。GPS座標と経路は計算された仮データで、実際の地図・GPS・音声・BLE通信は利用していません。

05/12の棒メーター、14のドット波形、26の送信メーター、45/47の声の表現に、状態連動のアニメーションを実装しています。待受・切断時に停止し、受信ミュートや音量0でも受信メーターが止まります。送信メーターは受信ミュートとは独立しています。OSの「視差効果を減らす」設定では静止表示になります。ドット文字は0〜9、未更新の「—」、3人の名前に対応し、距離スライダーで描画内容が変わります。

`npm test` は従来モデルに加えてPTT・位置・車列・GPS・色の整合性を検証します。`npm run test:studies` はHappy DOM上で実際の60案のReactコンポーネントを操作し、両画面・ドット数字・アニメーション適用条件・キャンセルを検証します。ブラウザ描画や実機の視認性を測定するテストではありません。

## 本体の文字入力と製品化前の検討

- 製品本体にソフトウェアキーボードは設けない。基本利用は名前入力なしで成立させる。
- グループ内のメンバーIDと識別色の対応を共有し、端末ごとに異なる色を割り当てない。接続し直しても同じ対応を保ち、退出で他のメンバーの色・順番を詰め直さない。色数の上限、重複、再参加、未登録端末は別途仕様化する。
- 人物ごとの図形による識別は採用しない。色帯・色面を使い、日光下や色覚差による識別性は実機で評価する。人数の上限や色が区別できない場合の扱いは別途検討する。
- 任意の表示名が必要な場合、停車中にスマートフォンアプリとBLE接続して設定する方式を、製品化前に別途検討する。ペアリング、対象端末の確認、保存先、グループへの共有範囲、アプリなし運用を設計する。今回はBLE／アプリ／名前同期を実装しない。
- 既存の操作デモにあるグループ名入力等は過去のUX検討用であり、最終製品の本体入力方式を示さない。今回の追記でそのデモの挙動は変更していない。

## 操作

- 左のデザイン選択で方向を切り替え。端末下部の「仲間・ライド・レーダー」または左右スワイプで画面切り替え。
- 右の「待受」にするとPTTを試せます。押して260ms後に仮の送信状態へ進み、離すと終了。短押し・切断・別画面への移動・フォーカス喪失で送信が残らない設計。
- 仲間の受信音に自分の送信を重ねられます。最大3人が発話中の場合だけ空き待ちに入り、押し直しは不要です。PTTを離せば自分の送信・待機を終了し、他の人の受信は継続します。
- アバターや名前を選ぶと、個別音量・消音・個別PTT。個別PTTは相手を選ぶだけでは送信せず、物理ボタンを想定したPTTで送信します。
- グループ設定でメンバー・全体音量・退出。参加からのデモ、グループ作成、空のグループにも対応。
- 20秒のデモは6場面を順に再生。端末を操作すると停止します。「動きを控えめに」とOSの動きを減らす設定に対応。

## 実行と確認

Node.js 22.13以上。

```sh
cd design/web-poc
npm ci
npm run dev -- --host 127.0.0.1
npm run typecheck
npm run lint
npm test
npm run build
```

Lintは作成したアプリ、状態モデル、変更したSliderを対象とします。テンプレートの未使用UI部品は対象外です。TypeScriptはプロジェクト全体を確認します。

車列画面のレイアウト回帰テストは、開発サーバーを起動した状態で `npm run test:fleet-layout` を実行します。インストール済みのChromeを使い、全60案の240・300・360px幅、390・320pxのモバイル画面、距離の変化・位置未更新・切断・地図拡大を描画して確認します。文字のはみ出し、文字同士の重なり、GPS番号の衝突を実際のブラウザ座標で検出し、レポートと各案の画像を `outputs/fleet-layout/` に保存します。接続先は `BASE_URL`、ブラウザチャンネルは `BROWSER_CHANNEL` で変更できます。DOMだけの操作テストは `npm run test:studies` です。

状態モデルのテストは、最大3枠・同時送受信・枠の空き待ち・送信許可前のリリース・切断・キャンセル後の参加コールバック・音量・位置の鮮度・文字数・デザイン切り替えを検証します。

同時通話は `npm run test:voice-mix` で確認します。比較ボード、全60案の2・3人受信、自分＋2人の同時送受信、最大3枠、押したままの空き待ち、リリース、ミュート、位置未更新、240・300・360pxの表示幅とモバイル表示を検証します。元の3案でも同時送受信と画面切り替えを操作します。画像とレポートは `outputs/voice-mix/` に保存されます。

## 確認範囲と残る検証

2026-09-06、Mac Chromeで3案の表示と390px/320px幅を確認。参加、作成、個別音量のキーボード変更、消音、個別PTT選択、短いPTT操作、切断時の送信抑止を操作して確認しています。

PTT長押しのタイマーは状態モデルと実装で確認していますが、実際の指での長押し、スワイプ、車内視認性、実機のキーイベントは別途受入確認が必要です。Webの表示・アニメーションはLVGLのFPS・メモリ・音声同時処理性能を証明しません。

WebMCPは対応環境のみ `read_roadweave_preview` と `set_roadweave_scenario` を登録します。今回のブラウザー接続はWebMCP検証能力を提供していないため、ツール契約の実行検証は未実施。通常のUI操作には影響しません。

## LVGLへ移すとき

- 状態モデル、表示文言、色、部品の配置を移植対象にする。CSSそのものは移植しない。
- Circleのアバターは円とラベル、声の輪は少数の輪郭にする。Pulseはラベル・バー・矩形を中心に構成。Compassは固定目盛りと小さな位置マーカーを分ける。
- 常時動かすのは発話マーカーなどの狭い領域。全画面のぼかしや影はWebの演出であり、実機では背景画像か単色へ置き換える。
- このプレビューの縮小表示は寸法の目安。実際の240×320パネル向けにはフォント・余白・描画領域を再配置して評価する。
- 走行中は物理PTTと音量操作を中心にし、グループ編集や細かな音量調整は停車中の操作として検討する。
- S3でOpus・無線・LVGLを同時に動かした実測を、P4などへ進む判断材料にする。

デザインの参考文脈はAppleの情報階層・直接操作・意味のある動き、およびXiaomiの大きな数字・柔らかい形状・状態遷移です。固有製品の画面や商標表現はコピーしていません。

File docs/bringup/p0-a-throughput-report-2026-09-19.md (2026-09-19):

# HaLow UDP最大転送速度の実証 — 2026-09-19

**最大観測はUDP payload 3.115 Mbit/s、試験headerを除くbody 3.073 Mbit/s。** 2 MHz・STA→APで得た。受信率99%以上・送信追随95%以上を60秒×3回で満たした最高目標は2.5 Mbit/sで、その実受信はUDP 2.411–2.417 Mbit/sだった。[事前計画](p0-a-throughput-plan-2026-09-19.md)に従い、現在のESP32-S3→SPI→MM6108経路の1/2 MHz・上下4条件と、理由を記録した追加探索1件を完了した。

## 計測条件

COM4をAP、COM5をSTAとして用い、COM6は無線停止のままにする。アンテナと既確認の使用場所を継続し、内蔵Wi-Fiを使わない。SPIはSDK設定40 MHz、consoleはnative USB Serial/JTAG。SDKのpacket単位INFOを抑え、throughput設定のみWARNへ変更した。

UDP payloadは1200 Bで、16 Bの試験headerと1184 Bの検証bodyからなる。echo待ちはなく、一方向streamを受信側でunique sequenceとbody検証により数える。primary goodputはEND前のactive unique受信bytesを、TX実測DATA時間とRX active spanの大きい方で割る。END後のtailを別記し、drainで受け切っただけの状態を持続合格へ変更しない。

最高合格候補はactive/final受信率99%以上、目標rateへの送信追随95%以上を60秒×3回で満たした点とする。飽和時の最大観測受信値は別に扱う。1 MHzは903.5 MHz、2 MHzは905 MHzで、中心周波数と周囲雑音も変わるため差を幅だけの効果と断定しない。

## 結果

| 幅 | 方向 | 最高合格目標rate | 60秒×3 RX UDP/body goodput | active/final loss | 最大観測RX UDP/body | 判定 |
|---|---|---|---|---|---|---|
| 1 MHz | STA→AP | 1.250 Mbit/s | 1.216–1.242 / 1.200–1.225 Mbit/s | 0–0.0263% / 同左 | 1.369 / 1.350 Mbit/s | PASS |
| 1 MHz | AP→STA | 1.000 Mbit/s（追加探索） | 0.99469–0.99484 / 0.98142–0.98158 Mbit/s | 0% / 同左 | 1.195 / 1.179 Mbit/s（初回飽和） | PASS |
| 2 MHz | STA→AP | 2.500 Mbit/s | 2.411–2.417 / 2.379–2.385 Mbit/s | 0.0132–0.0928% / 同左 | 3.115 / 3.073 Mbit/s | PASS |
| 2 MHz | AP→STA | 2.000 Mbit/s | 1.941–1.951 / 1.915–1.925 Mbit/s | 0–0.2137% / 同左 | 2.631 / 2.596 Mbit/s | PASS |

最大観測値は同一最終sourceの有効な本測定stageから選び、warmupは除外する。1 MHz上りは2 Mbit/s指定時にTX実績が約1.374 Mbit/sへ頭打ちとなり、4298/4298受信・body goodput約1.350 Mbit/sだった。送信追随が95%未満なので、その指定rateは合格候補にしない。無制限送信stageは4243/4243、RX UDP/body約1.349/1.331 Mbit/s。

同条件の60秒3反復では7601/7603、7760/7760、7716/7716を受信し、2欠落を保持した。1.250 Mbit/sは探索点のうち3反復を満たした最高目標rateで、絶対的な上限値ではない。今回の上限は受信損失より送信pathの追随不足で先に制約された。

1 MHz下りでは最初の128 kbit/s探索が392/400（2%損失）となり、規定どおり低負荷側へ探索を進めた。112 kbit/sの60秒3回は各700/700で、UDP約111999 bit/s、body約110506 bit/sだった。

飽和stageの結果を見る前に、追加条件を固定した。有効な飽和stageがRX 512 kbit/s以上かつactive/final受信率99%以上なら、低負荷での失敗と高負荷での成功が両立し、損失が負荷に対して単調に増える前提では探索できないため、512・1000・2000・4000・8000 kbit/sを開始点とする追加探索を1ケースだけ行う。30秒探索・2段階絞込み・60秒3反復の基準は同じとし、元の損失と結果を残す。追加試験の失敗を理由に再追加はしない。この条件を満たさなければ2 MHzの予定試験へ進む。

実際の飽和stageは3759/3759、RX UDP/body 1.195422/1.179483 Mbit/sで条件を満たしたため、追加探索を1回実施した。1 Mbit/sの60秒3回は6219/6219・6217/6217・6218/6218で、body 0.981424–0.981580 Mbit/s。1.25 Mbit/s指定では送信実績1.153575 Mbit/s（92.29%）となり、追随条件を満たさなかった。追加caseの無制限送信は3626/3626、UDP/body 1.151408/1.136056 Mbit/sだった。

元の112 kbit/sを機器の最大速度とは扱わず、初期の損失変動で探索が低負荷側へ限定された結果として残す。初回の128 kbit/s・2%損失と、追加1 Mbit/s・3回無欠落は両方有効な観測であり、常に1%以下の損失となることまでは証明していない。

2 MHz上りは2.5 Mbit/sの60秒3回で15071/15085・15113/15115・15102/15110を受信した。合計24欠落を保持する。4 Mbit/s指定時のTX実績3.121515 Mbit/s、9755/9755、RX UDP/body 3.114509/3.072982 Mbit/sが同条件の最大観測値だった。無制限送信は9687/9695、UDP/body 3.092445/3.051213 Mbit/s。3 Mbit/s指定も送信追随92.38%で未達となり、ここでも送信pathの追随不足が合格候補を制限した。

2 MHz下りは2 Mbit/sの60秒3回で12138/12164・12187/12187・12193/12206を受信し、計39欠落。2.5 Mbit/s指定では送信追随93.59%で未達となった。無制限送信は8244/8244、UDP/body 2.631015/2.595935 Mbit/sで同条件の最大観測値だった。今回の4条件では、いずれも最高合格候補より上の探索点で送信追随不足を観測した。

## 実機で見つかった不具合

最初のsmokeでは、短いARM命令がUSBから分割して読み出された際に `fgets` の改行未到着をtoo_longと誤判定した。source `41929f5` の `smoke-1mhz-sta-to-ap` は測定開始前・stage0でFAILとなった。元ログを保存し、throughput値には含めない。

`b3964b5` は改行までbyteを蓄積し、一時的なEOFでも断片を保持する。真のbuffer上限を超えた場合だけ破棄するよう修正した。初回FAILでも両台のSTOP ACK・radio shutdown・DONEは記録されており、通信測定失敗と無線停止状態を分ける。

修正後smokeは128 kbit/s・5秒の5stageすべてで命令・計数・3秒drainが成立した。最初の4回は67/67、最後は61/67で6欠落し、短い確認試験の品質基準を満たさなかった。両端は5stageを完遂し無線停止・PASS・DONE。この有効な損失観測を保持し、条件を緩めず30秒探索／60秒確認へ進む。

最初の本測定 `full-1mhz-sta-to-ap` はstage10のRX summary待ちで9秒timeoutとなった。summaryは後続のcleanup出力が発生した時点で届き、7666/7666・drain3.029986秒を示していたが、3反復は完了していないため元のFAILを保持する。

このsummaryはCRLF込み512 Bで、USB packet64 Bの倍数だった。固定IDFのUSB Serial/JTAG VFSは、64 B終端の転送に0 B packetを追加しないとhost bufferに残ることを明記し、`fsync`の完了待ちで追加flushする実装を持つ。修正 `655c5bb` はsummary等の制御出力後にstdio flushとVFS fsyncを行う。

修正後1 MHz上りのstage10でも512 Bのsummaryとなり、7760/7760を記録。今回はDRAIN ACKからhost到着まで3.000秒、device drain3.029996秒で正常に取得できた。旧caseは同じ512 Bが約9.047秒後のcleanup出力まで滞留していた。host側もDRAIN ACKを確認し、同時capture済みのsummaryを捨てずに扱う回帰修正を追加した。

## 計数・性能の解釈

- TX成功だけを受信goodputにしない。送信失敗、受信損失、duplicate、tail、invalidを分離する。
- 負荷生成の独立skipped counterはなく、送信実績/目標rateで追随不足を判定する。送信pathの限界をRFだけの限界にしない。
- 低負荷で観測した損失の原因、および送信追随不足に対するESP32 CPU・lwIP・SPI・無線airtimeの寄与は未分離。今回の測定結果を残し、追加の性能最適化は行っていない。
- IDLE taskを動かすため、送受信loopは約50 msごとに1 tickのblocking yieldを行う。body検証やlwIP処理も含む今回の経路の実効値である。
- 有限時間・探索点の範囲に制約される実測で、PHY理論最大、TCP、音声遅延、長時間持続能力を証明するものではない。

8時間運転は未実施。実電源断50回は[Issue #27](https://github.com/rimtty/RoadWeave/issues/27)、必要な計測器購入・電源計測は[Issue #28](https://github.com/rimtty/RoadWeave/issues/28)の延期状態を維持し、P0-A全体を完了とはしない。

## 証拠と終了状態

[実測データ](logs/2026-09-19-throughput/README.md)に各stageの独立再解析、失敗capture、安全に抽出したeventsと原本hashを保存する。[firmware manifest](logs/2026-09-19-throughput/firmware-manifest.json)にはbinary SHA256・非秘密設定・個体別flash証拠を記録する。private原ログと初回実行tools snapshotも保持し、host checkoutを実機sourceと取り違えない。

[再実行手順](halow-throughput-runner.md)は幅・方向ごとに有限captureを作成し、STOPから正常停止まで確認する。追加探索は既存runnerのrate指定のみを変え、測定中にFW・判定実装は変更していない。

| 成果 | 実測・確認したsource | 保存 |
|---|---|---|
| 計画 | `9480d1c` | [PR #37](https://github.com/rimtty/RoadWeave/pull/37)、merge `0a618437` |
| stream firmware・USB入力/終端修正 | `655c5bb30ed44d33235f511105eac329ae50f058` | [PR #38](https://github.com/rimtty/RoadWeave/pull/38)、merge `6295102` |
| host探索・counter照合・summary受信修正 | `5a12d4dddf3cbe4675819fd9f96c584a967f123d` | [PR #39](https://github.com/rimtty/RoadWeave/pull/39)、merge `ed29310` |

最終sourceでAP/STA×1/2 MHzの4構成をbuildした。hostは正常・損失・不整合・期限・同時到着summary等の16テストを通過している。

終了時はCOM4/5を保存済みの通常 `aa58241` 1 MHz DHCP firmwareへ書き戻し、COM6は同sourceのSTA2を維持した。3台の160秒通信を再検査し、warmup後はSTA1 588/588、STA2 587/587、同時測定窓146.859秒でPASS。全3台のSTOP ACK・RUN_END・radio shutdown・PASS・DONEを確認した。[最終状態の証拠](logs/2026-09-19-throughput/final-state.json)に個体・binary SHA・復元flashの照合を残す。

現在は全3台無線停止。RF無効のfirmwareへ変更したわけではなく、次回reset／再給電すると通常の1 MHz DHCP試験が最大600秒の設定で始まる。最大速度測定用firmwareとは別のsourceであることを最終状態にも明記した。

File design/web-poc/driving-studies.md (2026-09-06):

# 走行用UI / 17–32の設計メモ

## 同時通話への更新

音声ストリームを混合する前提で、Web PoCは自分を含む最大3人の同時発話に対応する。2〜3人の発話時には全話者を固定の行に並べ、各人の名前（Color Identity案では色名）・距離・受信メーターを一緒に表示する。距離の対象は自動で巡回させず、明示的に選択する。送信中も受信者の表示を残し、PTTを離すと自分だけを終了する。

3枠を使用中の場合だけ送信の空きを待つ。PTTを押し続けていれば枠が空いたときに送信準備へ進み、離せば待機を取り消す。受信音量やミュート、GPSの鮮度は発話枠の使用状況と分離する。実際のIPストリーム混合、許可の調停、音量正規化、遅延・エコーの評価は実装側で別途確認する。

## 目的と優先順位

トランシーバーの音声を主経路にし、画面は短い確認を補助する。常に眺めたり、操作先を探したりする構成にしない。32案の比較ボードそのものは停車中のデザインレビュー用。

| 優先 | 運転手の問い | 表示方針 |
| --- | --- | --- |
| 1 | 受信・送信・待受・未接続のどれか | 上端の定位置に日本語と記号を併記。切断時は送信不可を中央に優先表示 |
| 2 | 誰の声か、誰に送るか | 受信中は短い呼び名、送信中は宛先を大きく。顔・色だけで識別させない |
| 3 | 誰が前後どちらに何mか | 数字とm・前後・対象者を関連づける。矢印は上下の相対前後で、右左折案内ではない |
| 4 | 通信が維持されているか | 接続人数は下端。通常時の電池率・時刻・詳細メンバー・設定は省略 |

受信中は名前と距離を中心にする。待受では次の送信先、送信中では自分からの宛先を表示する。接続が切れたら以前の距離を現況のように見せない。位置が未更新でも音声が届くケースでは、AKIと受信中を残し、距離を「—m」「位置未更新」に置き換える。距離は仲間の仮の相対位置であり、安全車間・衝突リスク・走行可否の判断を表さない。

## 表示と操作

- 240×320を論理サイズにした縦長3:4画面。CSSのコンテナ単位でカード幅に比例させる。240px幅換算で状態24px、主情報44–72px、補助14–18pxが目安。図形化したドット数字は文字サイズ指定ではなく、大きな図形として同じ領域に置く。
- このpxはブラウザの論理サイズであり、視距離に対する必要文字寸法の規格値ではない。物理寸法・視角・取付位置の評価は別に必要。
- 状態は文字・記号・色を組み合わせる。赤や橙だけを根拠に意味を読み取らせない。
- 名前と数字を背景に重ねない。名前にグラデーションや細いドット書体を使わない。ドットは太い数字か枠だけに限定し、日中・暗色・通常文字の比較案を用意する。
- 波形や輪の装飾は静止。自動カルーセル・スクロール文字・点滅・自動並べ替えを入れない。
- 短い呼び名を停車中に設定する想定。実装時は長い名前・同名・日本語・欧文を検証し、重要な名前を単純に省略しない。20の「アキ」はAKIと同一のサンプル人物。
- 走行用画面にはソフトキーを置かず、物理PTT・物理音量の操作を前提にする。グループ参加・宛先の変更・個別音量調整は停車中の画面にまとめる設計仮説。
- 追加16案は静止したUI/UX検討サンプル。物理キー・状態遷移・音声通知・走行判定の実装は追加していない。既存の操作デモもそのまま保つ。

## 16案

| No. | 名前 | 比較する設計 |
| --- | --- | --- |
| 17 | Clarity | 白地、名前中央、方向と距離を下段に集約 |
| 18 | Broadcast | 暗色、受信帯、名前と距離の2段 |
| 19 | Voice Seal | 静止した輪を目印に、名前を大きく |
| 20 | Callsign | 大きな日本語の呼び名と左揃え |
| 21 | Lead | AKIを固定し、前方120mを最大表示 |
| 22 | Front / Rear | 上段にAKIの120m、下段にRENの85m |
| 23 | In Line | 自分を中央に置いた縦の前後関係 |
| 24 | Direction | 左の前方記号、距離、下部の発話者帯 |
| 25 | Ready | 待受、次の宛先は全員、物理PTTの案内 |
| 26 | On Air | 送信中、あなたから全員へ、離すと終了 |
| 27 | Link Lost | 未接続、送信不可、再接続中 |
| 28 | Position Hold | AKI受信中を維持し、未更新の位置数値を隠す |
| 29 | Dot / Bold | 黒地、大きく太いドット数字、赤い受信印 |
| 30 | Dot / Daylight | 明るい背景、濃い青のドット数字 |
| 31 | Dot / Amber | 暗い背景、琥珀色の数字、通常文字の名前 |
| 32 | Dot / Frame | ドットは枠だけ、名前と距離は通常の太字 |

## 根拠と限界

[Transport Canada: Guidelines to Limit Distraction from Visual Displays in Vehicles](https://tc.canada.ca/en/road-transportation/stay-safe-when-driving/transport-canada-guidelines-limit-distraction-visual-displays-vehicles) を参照。簡略なdriver mode、走行時の操作制限、装着位置・日光・夜間などを含む評価の考え方を採用した。同資料は双方向無線通信を運転そのものとは別のコミュニケーション作業として扱っている。画面を大きくするだけで注意分散が解消されるという前提にはしない。

上記資料は車載画面の参考情報であり、RoadWeaveの実機や二輪用途への適合・安全性・規格準拠を示すものではない。文字サイズとレイアウトは今回の設計判断。静止画だけで運転中の安全を判定しない。

次の評価は停車状態とシミュレータから始める。実パネルの物理寸法・距離・角度・日光反射・夜間輝度・振動・偏光レンズの条件を揃え、発話者、前後、距離、送受信状態を正しく短時間で識別できるか比較する。位置欠損、音声断、長い名前、日本語、同名、受信と送信の切替も含め、誤読・再確認・操作の必要性を記録する。ドット数字と連続した太字の比較を行い、読みにくい装飾は削る。

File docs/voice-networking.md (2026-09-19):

# 音声ネットワーク設計

更新日: 2026-09-06  
Protocol working name: RWP/0.1

## 1. 製品体験

RoadWeaveは「インターネットなしのDiscord風group voice」を目指す。ただし最初からfull-duplex multi-speakerにしない。

1. P0: 1対1 half-duplex IP-PTT
2. P1: group内で1人だけ発話するfloor-controlled PTT
3. P4: targeted PTT、個別mute/gain
4. 実測余力がある場合だけ最大2 active speakersのvoice room
5. P5: group recording

この順番ならAEC、複数decode/mix、RF競合を一度に持ち込まず、protocolの拡張余地だけ先に確保できる。

## 2. Network model

- HaLow AP/STA、local IPv4、internet gateway不要
- WPA3-SAEをlink layerの最低要件
- voiceはUDP、controlは最初UDP + idempotent message
- Coordinatorがgroup membershipとfloor leaseを管理
- Node IDは製造時IDとuser-visible callsignを分離
- Group secretからsession keyを派生するapplication encryptionはP4までに設計review

WPA3は無線linkを守るが、targeted PTTのprivacy boundaryをAP任せにしない。private/subgroup payloadは対象鍵で暗号化するか、対象peerだけへunicastする。

## 3. Traffic classes

| Class | 例 | Priority | Delivery |
|---|---|---:|---|
| C0 realtime control | PTT_START/END、floor grant | highest | repeated/idempotent |
| C1 voice | codec frames | high | loss tolerant、再送しない |
| C2 presence/position | peer/GPS 1 Hz | medium | newest wins |
| C3 config/log | settings、record index | low | reliable/task queue |
| C4 map/storage | PMTiles read/sync | lowest | audio deadline時にpause |

## 4. Packet header draft

Network byte order。wire formatはC structのpaddingへ依存させず、明示serializeする。

```text
magic          u16   0x5257 ("RW")
version        u8    0x01
type           u8    CONTROL / VOICE / POSITION / EVENT
codec          u8    VOICE時のpayload形式。0=IMA-ADPCM 16 kHz/20 ms、1=Opus。他typeは0
flags          u16   encrypted, start, end, fec, recording_hint...
header_len     u16
group_id       u32
sender_id      u32
target_type    u8    GROUP / NODE / SUBGROUP
target_id      u32   0 for GROUP
stream_id      u32   new value per PTT session
sequence       u32
capture_time   u32   monotonic ms modulo 2^32
payload_len    u16
payload        bytes
auth_tag       bytes optional by security profile
```

`codec`をheaderに持つことで、P0のIMA-ADPCMからP4のOpusへ移る際にprotocol versionを上げずに混在受信できる。受信側は未知のcodecを黙って捨て統計へ回す。

`stream_id + sequence`でreorder/lossを検出する。wall-clock未同期でも再生できるよう、音声はmonotonic capture timeを使う。録音時にGNSS UTCとの対応eventを別に残す。

## 5. Codec profiles

| Profile | Codec | Sample/frame | 目的 |
|---|---|---|---|
| P0 | IMA-ADPCM 64 kbps | 16 kHz / 20 ms | 実装が軽く、network/audio測定を分離 |
| Product speech | Opus 8〜12 kbps | 16 kHz / 40 ms候補 | airtimeと音質のbalance |
| High quality | Opus 16〜24 kbps | 16/24 kHz / 20〜40 ms | RF/CPU余力時のみ |

Opusはspeech向け低bitrateを選べるが、packet overhead、retransmission、PHY airtimeはcodec bitrateと同じではない。[Opus documentation](https://opus-codec.org/docs/)

## 6. Floor control

```text
IDLE
  -> PTT_DOWN: FLOOR_REQUEST(stream_id, target)      [REQUESTING]
  -> GRANTED: local beep/indicator, begin voice      [TALKING]
  -> DENY or no answer after retries, PTT still held: busy tone once,
     re-request every deny_retry_ms up to busy_wait_max_ms  [BUSY_WAIT]
  -> PTT_UP: PTT_END x3, stop capture                [ENDING] -> IDLE
  -> lease expiry/link loss: force stop and return IDLE
```

BUSY_WAIT は host simulator（`firmware/sim`）で見つかった 2 つの穴への対処: 相手の PTT_END が全損したときに
lease 失効（750 ms）まで待って再要求する経路がなかったこと、REQUEST/GRANT がロスで往復しなかったときに
PTT を押したままでも二度と要求しなかったこと。押している間だけ再要求し、離せば即 IDLE。

暫定timer:

- grant target: 100 ms以内
- lease: 750 ms、voice/control packetでrenew
- max continuous PTT: 120 s、その後warning/renew
- PTT_ENDを3回短間隔で送るが、受信側はidempotent
- deny_retry: 250 ms、busy_wait_max: 5 s（実装既定値、`floor_cfg_default()`）

同時requestはCoordinator受信時刻とsender IDでdeterministicに決める。緊急優先は誤操作と権限設計が必要なためP0/P1では入れない。

## 7. Jitter/loss

- P0 jitter target: 20〜40 ms、adaptive上限80 ms
- late packetは再生せず統計へ
- voice UDP再送なし。将来FECはloss測定後
- sequence gapでPLC/短いsilenceを生成
- stream切替時はold streamを即flushし、speaker popを抑制

測定する指標:

- PTT downから相手の最初の可聴音まで
- capture-to-play p50/p95/p99
- packet loss、late loss、burst length
- jitter buffer underrun/overrun
- RF retry、RSSI/SNR、airtime

PTTから最初の再生までを共通クロックで測る治具・解析ツールは[6台音声遅延の測定準備](bringup/voice-latency-measurement.md)を参照。端末内の区間ログは別途実装し、異なる端末の時計を直接引き算しない。

## 8. Individual mute/volume

mute/gainは受信側のlocal policyであり、相手へ状態を通知しなくても成立する。

```text
sender_id -> mute? -> decode -> per-user gain -> mix -> limiter -> speaker
```

- gainは0〜150%、UIは0〜100%を基本
- muteはpersistent setting、current speaker muteは即時
- master volumeとuser gainを分離
- limiterを最後段に置き、2 stream合成時のclippingを防ぐ

## 9. Targeted PTT

target modes:

- `GROUP`: 全員
- `SUBGROUP`: LEADERS、REARなど事前定義
- `NODE`: 指定1台

UIは運転中に深いmenuを要求しない。短押しは直前target、長押し/停車中操作でtarget変更、画面と音で`ALL / LEADERS / CAR-03`を確認する。

## 10. Recording roadmap

PCMを混ぜた1本のfileだけでなく、encoded frameとmetadataを保持する。

```text
session manifest
  group_id, participants, start UTC, device versions
audio records
  capture time, sender_id, stream_id, sequence, opus payload
events
  PTT, join/leave, mute policy, GPS time anchor
```

利点:

- 全員/特定senderだけを再生
- GPS logやdashcamと同期
- 後からmix levelを変更
- packet lossを記録として識別

初期状態OFF、REC中の常時indicator、参加者通知、storage暗号化、export/deleteを製品要件にする。

## 11. Group size

暫定製品目標は8台、protocol上限16台。これはHC01の接続上限を断定する値ではない。次を満たした最小値を正式specにする。

- 1 active speaker + 全node 1 Hz positionでp95 latency <=150 ms
- group churn中もfloor stateが壊れない
- Coordinator CPU/RAMとairtimeに30%以上の余裕
- Japan lineのairtime/Duty要件を満たす

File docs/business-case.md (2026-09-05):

# 事業性の再検討（v2、2026-09-06）

前提: [製品定義 v2](product-definition-v2.md)、[BOM v2](bom.md)。金額は税別、為替 USD 1 = JPY 150、開発人件費は別枠。

## 1. 原価（BOM v2、MRF61_A 日本ライン）

| 数量 | COGS/台（計画値） |
|---:|---:|
| 100 台 | 19,700 円 |
| 1,000 台 | 11,700 円 |
| 10,000 台 | 8,000 円 |

## 2. 価格と粗利

| 直販売価（税別） | 100 台 | 1,000 台 | 10,000 台 |
|---:|---:|---:|---:|
| 29,800 円 | 34% | 61% | 73% |
| **34,800 円** | **43%** | **66%** | **77%** |
| 39,800 円 | 51% | 71% | 80% |

販売店経由（卸値 = 売価の 60%）の場合、34,800 円なら手取り 20,880 円で、100 台原価では粗利 6%、1,000 台原価で 44%。
**100 台ロットは直販以外では成立しない。**

競合の実勢: デジタル簡易無線（登録局）25,000〜40,000 円、バイク用メッシュインカム 35,000〜50,000 円。
位置・隊列表示とグループ UI を持つ製品はこの帯にないため、34,800 円は説明できる。29,800 円は 1,000 台ロット以降の価格。

## 3. 初期費用（NRE）

| 項目 | 見積り | 備考 |
|---|---:|---|
| Rev.A 試作（基板 2 版 × 5〜10 台） | 50〜150 万円 | 4 層、部品、実装 |
| RF / audio / GNSS 試験治具 | 30〜100 万円 | conducted 試験系、音響治具 |
| 認証（アンテナ追加登録、PSE 確認、EMC 自主試験） | 30〜100 万円 | MRF61_A の認証を利用、機器単体の無線認証は不要 |
| 筐体: 100 台までは切削 / 3D プリント | BOM に含む | 金型なし |
| 射出成形金型（1,000 台判断時） | 300〜800 万円 | ここが最大の投資 |
| 初回量産の不具合準備金 | 発注額の 5〜10% | |

金型前の NRE 合計: **110〜350 万円**。金型後: **410〜1,150 万円**。

## 4. 損益分岐（人件費除く）

1 台あたりの貢献利益 = 売価 − COGS。

| シナリオ | 貢献利益/台 | 金型前 NRE 回収台数 | 金型込み NRE 回収台数 |
|---|---:|---:|---:|
| 直販 34,800 円、100 台原価 | 15,100 円 | 73〜232 台 | — |
| 直販 34,800 円、1,000 台原価 | 23,100 円 | — | 178〜498 台 |
| 卸 60%、1,000 台原価 | 9,180 円 | — | 447〜1,253 台 |

読み方: **初回 100 台（直販）は NRE の一部を回収する市場テスト**であり利益は出ない。
**1,000 台ロットを直販中心で 1 年以内に売り切れるなら成立**、卸中心なら 2 ロット目以降。

## 5. 売り方の前提

- 1 グループ = 2〜6 台の同時購入。3 台セット（99,800 円）など**セット売り**で客単価を上げる。
- 初期顧客: ツーリングクラブ、ラリー/走行会運営、イベント・レンタル（B2B）。B2B は台数がまとまり、価格感度が低い。
- 個人向け直販は Web + 動画。販売店は 1,000 台ロット以降。

## 6. リスク（事業側）

| リスク | 影響 | 手当て |
|---|---|---|
| MRF61_A の単価・MOQ が仮定（4,200 / 3,000 / 2,300 円）より高い | COGS +1,000〜2,000 円 | RFQ（Issue #10）で確定するまで価格を公表しない |
| 13 dBm での実効到達距離が期待（1 km）を下回る | 製品価値の低下 | P2 で実走計測、中継（マルチホップ）を P3 以降の差別化に |
| 2.8 インチ表示の日光下視認性 | UX | Rev.A 前に 2〜3 種を実物比較（display-selection.md） |
| 技適・アンテナ登録の遅延 | 発売遅延 | 認証登録済みアンテナで発売、車載高利得は後追い |
| 100 台の切削筐体の品質 | 初期評価 | 3D プリント + 塗装で見た目を担保、IP54 は簡易試験 |

## 7. 結論（go / no-go の基準）

- **技術**: 6 人グループ、2 話者同時、Opus、2.8 インチ LVGL、GPS 隊列は現行 MCU と無線で成立する（実測根拠あり）。
- **事業**: 直販 34,800 円で 1,000 台/年が見込めるなら成立。判断材料は P2 実走の到達距離と、100 台ロットの直販実績。
- **go の条件**（P2 完了時に判断）: (1) MRF61_A RFQ が COGS 仮定の +1,000 円以内、(2) 実走で見通し 500 m / 市街 200 m 以上、
  (3) 100 台の予約または B2B 引き合い 30 台以上。
- 満たさない場合は B2B（イベント・レンタル）専業か、無線モジュール込みの開発キット販売に縮小する。

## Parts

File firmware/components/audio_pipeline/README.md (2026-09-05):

# audio_pipeline component

- `adpcm.[ch]`: IMA ADPCM（16 kHz mono、4 bit/sample）。20 ms block = 4 byte state header + 160 byte = 164 byte（65.6 kbps）。
  block ごとに predictor state を持つので、packet loss 後も次の block を独立に decode できる。
- `jitter.[ch]`: sequence 順の固定 slot jitter buffer。prefill、late/duplicate/gap/underrun 統計、late 頻発で深さを +1 frame、
  過剰深さが続けば -1 frame（min 20 / max 80 ms）。stream 切替で flush。

ホストテスト:

```bash
make -C firmware/components/audio_pipeline/test_host test
```

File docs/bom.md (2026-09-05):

# BOM v2 と数量別コスト仮定

更新日: 2026-09-06（v1: 2026-09-02）  
通貨: 日本円、税別。[製品定義 v2](product-definition-v2.md) に合わせて 2.8 インチ静電容量タッチ表示と MRF61_A（日本ライン）を主構成にした。

## 1. 読み方

これは発注見積ではなく、設計判断のための should-cost モデルである。100/1,000/10,000 台の各列は同一設計をその数量で一括生産した場合の 1 台当たり仮定。
為替は **USD 1 = JPY 150**、通常歩留まり、標準梱包を想定する。

含むもの: 電子部品、PCB、実装、筐体（100 台は切削/3D プリント、1,000 台以上は成形）、工場機能試験、標準梱包、歩留まり・初期不良準備金。
含まないもの: 開発人件費、試作、治具 NRE、金型 NRE、認証・EMC 試験、物流、関税、販売手数料、消費税、microSD カード、車外マグネットアンテナ、車載電源アダプタ。

## 2. 日本ライン（MRF61_A、2.8 インチ CTP）= 製品主構成

| 項目 | 代表仕様 | 100 台 | 1,000 台 | 10,000 台 | v1 比 |
|---|---|---:|---:|---:|---:|
| HaLow module | MegaChips MRF61_A（技適済み、13 dBm）**RFQ 前の仮値** | 4,200 | 3,000 | 2,300 | +2,400 / +1,550 / +1,100 |
| MCU module | ESP32-S3-WROOM-1-N16R8 | 650 | 500 | 410 | 0 |
| GNSS | UART GNSS + antenna | 900 | 650 | 520 | 0 |
| Display | 2.8 in IPS 240×320 + 静電容量タッチ（FPC、FT6336 系） | 1,800 | 1,200 | 850 | +800 / +500 / +330 |
| Backlight driver | LED boost driver + PWM | 120 | 80 | 60 | new |
| I2S mic | T5848 / INMP441 級 | 180 | 110 | 80 | 0 |
| I2S amp | MAX98357A / 同等（5 V 給電） | 180 | 110 | 75 | 0 |
| Speaker | 4 ohm 2 W + チャンバ | 400 | 280 | 200 | +50 / +40 / +30 |
| RF antenna / coax | 920 MHz 認証登録アンテナ + SMA | 950 | 650 | 430 | 0 |
| Battery | protected 1S 3,000 mAh | 1,100 | 750 | 520 | 0 |
| Power parts | charger / power-path、3.3 V buck、5 V boost、gauge | 850 | 570 | 400 | 0 |
| UI / connectors / protection | USB-C、ESD、PTT（大）、VOL±、電源/機能、LED | 600 | 400 | 280 | +100 / +70 / +50 |
| microSD socket | カードは別売 | 100 | 70 | 45 | 0 |
| PCB | 4 層、ENIG | 900 | 450 | 260 | 0 |
| SMT / assembly | 両面実装 | 1,000 | 550 | 350 | 0 |
| Enclosure | 2.8 in 窓、切削/3D プリント（100）→ 成形（1,000〜） | 2,700 | 800 | 450 | +200 / +100 / +50 |
| Mechanical | IP54 gasket、レンズ（AR）、fastener、label | 400 | 250 | 160 | +100 / +60 / +40 |
| Factory test | flash、audio、GNSS、touch、RF conducted（JP band） | 800 | 430 | 250 | +100 / +50 / +30 |
| Packaging | 本体標準梱包 | 350 | 220 | 150 | 0 |
| **小計** |  | **18,180** | **11,070** | **7,790** | +3,870 / +2,450 / +1,690 |
| Yield / warranty reserve | 8% / 5% / 3% | 1,454 | 554 | 234 | |
| **想定 COGS / 台** | 丸め前 | **19,634** | **11,624** | **8,024** | |
| **計画値 / 台** | 意思決定用丸め | **19,700** | **11,700** | **8,000** | v1 JP ライン 18,000 / 10,700 / 7,400 |

ソフトウェアのロイヤリティはない（ESP-IDF: Apache-2.0、LVGL: MIT、Opus: BSD、Morse SDK: Apache-2.0）。Wi-Fi CERTIFIED HaLow は任意。

## 3. HC01 V2 ライン（海外向け / 開発主系、参考）

MRF61_A の行を HT-HC01 V2（1,800 / 1,450 / 1,200 円）に置き換え、認証アンテナを汎用品（950 → 700 円級）にした場合:
**計画値 17,100 / 9,950 / 6,750 円**。日本国内では販売できない。

## 4. 変更の内訳（v1 → v2）

- 表示を 1.47 インチ非タッチから 2.8 インチ静電容量タッチへ: +920 / +580 / +390 円（driver 込み）
- スピーカー・ボタン・筐体・機械部品の格上げ（モックの「大きな PTT」「高出力スピーカー」「IP54」）: +450 / +270 / +170 円
- MRF61_A は v1 の日本ライン仮定と同じ（RFQ 待ち）

## 5. 売価 34,800 円（税別、直販）の粗利感度

| | 100 台 | 1,000 台 | 10,000 台 |
|---|---:|---:|---:|
| COGS/台 | 19,700 | 11,700 | 8,000 |
| 粗利額/台 | 15,100 | 23,100 | 26,800 |
| 粗利率 | 43% | 66% | 77% |

卸（売価の 60%）の場合は手取り 20,880 円で、100 台原価では粗利 6%。詳細は [business-case.md](business-case.md)。

## 6. NRE とキャッシュ上の注意

| 項目 | 初期レンジ仮定 |
|---|---:|
| Rev.A 回路/PCB 試作 2〜10 台 | 50〜150 万円 |
| RF/audio/GNSS 試験治具 | 30〜100 万円 |
| 認証（アンテナ追加登録、PSE、EMC 自主試験） | 30〜100 万円 |
| 射出成形金型 | 300〜800 万円 |
| 初回量産の不具合対応準備 | 初回発注額の 5〜10% |

100 台では金型を償却しない。1,000 台の判断時に金型を発注する。

## 7. PoC 追加購入（6 node 試験、Issue #20）

| 品目 | 数量 | 目安 |
|---|---:|---:|
| XIAO ESP32S3（header 付き） | +3 | 7,500 円 |
| Wio-WM6180 | +3 | 7,500 円 |
| 2.8 in ILI9341 SPI + XPT2046 タッチ（PoC 用） | 2 | 1,900 円 |
| MAX98357A / スピーカー / PTT（追加分） | +3 組 | 3,000 円 |
| 合計 |  | 約 20,000 円 |

MRF61_A の評価キットが入手できれば WM6180 の追加は 3 台にとどめ、6 node 試験の半分を MRF61_A で行う。

## 8. コストダウン順序

1. MRF61_A、表示、battery、antenna を RFQ して実価格に置換
2. EVT で電源と audio の過剰 spec を削る
3. 4 層基板面積と実装面数の最適化
4. 1,000 台以上で custom enclosure、speaker chamber、flex/connector 削減
5. 10,000 台の見込みが立ってから ESP32 module-to-chip 化を検討

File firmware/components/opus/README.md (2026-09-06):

# opus component

libopus を ESP-IDF component としてビルドする。fixed-point、float API 無効、DRED/OSCE/Deep PLC 無効。

ソースは commit しない。使う前に取得する:

```bash
firmware/components/opus/fetch-upstream.sh   # xiph/opus v1.5.2 を ./upstream へ clone
```

Windows PowerShellではRepoルートから`.\firmware\components\opus\fetch-upstream.ps1`。
取得済みの場合もtag `v1.5.2`と未変更の作業ツリーを確認する。

ベンチ結果は [docs/bringup/opus-bench-2026-09-05.md](../../../docs/bringup/opus-bench-2026-09-05.md)。
license は BSD-3-Clause（`upstream/COPYING`）。

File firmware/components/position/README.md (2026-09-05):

# position component

P3 の位置ビーコンと隊列表示のロジック（`docs/gps-and-maps.md` §2〜§4）。GNSS モジュール到着前に pure C で先行実装。

- `pos_beacon_t` の 28 byte wire format（group/sender は RWP header 側）。fix なしや (0,0) は `pos_beacon_valid()` が弾く
- local ENU（equirectangular、float、antimeridian 対応）、距離・方位、進行方向への射影（Convoy の +120 m / -620 m）
- peer table（16 台、newest-seq wins、3 s で dim / 10 s で stale、expire）

```bash
make -C firmware/components/position/test_host test
```

未実装: breadcrumb ring buffer と route projection（§4）。P3 で GNSS 実測と一緒に入れる。

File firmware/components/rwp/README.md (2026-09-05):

# rwp component

RWP/0.1 wire format と floor control の pure C 実装。ESP-IDF に依存しないため、ホスト側で単体テストできる。

- `include/rwp.h` / `rwp.c`: 36 byte 固定ヘッダの serialize / parse、CONTROL payload、wrap-safe sequence 比較
- `include/floor.h` / `floor.c`: node 側 PTT 状態機械（IDLE / REQUESTING / TALKING / ENDING）と coordinator 側 floor table、同時 request の決定的調停
- `test_host/`: ASan/UBSan 付きのホストテスト

仕様は [docs/voice-networking.md](../../../docs/voice-networking.md) §4 と §6 を source of truth とする。

## ホストテスト

```bash
make -C firmware/components/rwp/test_host test
```

## 使い方（node 側）

```c
floor_node_t fn; floor_node_init(&fn, NULL, initial_stream_id);
uint32_t act = floor_node_step(&fn, FLOOR_EV_PTT_DOWN, now_ms);
if (act & FLOOR_ACT_SEND_REQUEST) send_control(RWP_CTRL_FLOOR_REQUEST, fn.stream_id);
// 10 ms 周期で FLOOR_EV_TICK、受信に応じて FLOOR_EV_GRANT / FLOOR_EV_DENY、
// voice packet 送信ごとに FLOOR_EV_VOICE_SENT を入れる。
```

時間は monotonic ms を注入する。wrap は考慮済み。

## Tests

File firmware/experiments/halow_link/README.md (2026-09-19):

# XIAO + Wio-WM6180 two-node link bench

ESP-IDF **v5.4.4**, `morsemicro/halow` **2.11.2-esp32-2**. Based on the pinned
official `softap` / `sta_connect` examples and Porting Assistant SPI transport.
This project uses only the SPI-connected MM6108 for wireless communication.
It does not initialize ESP32 internal 2.4 GHz Wi-Fi or use a 2.4/5 GHz WLAN link.

## Default: no RF transmission

`RW_LINK_RF_ENABLE` defaults to **off**. Both roles run the same preflight:

- Read the embedded firmware and BCF TLV containers through their EOF markers.
  This checks file structure, not calibration correctness or radio startup.
- Initialize SPI, read MM6108 ID 100 times with transport CRC validation.
- Deinitialize the bus and hold WM6180 RESET_N low.
- Print `RW_LINK_PREFLIGHT=PASS/FAIL`, `RW_LINK_RADIO_RESULT=NOT_RUN`, `RW_LINK_DONE`.

Preflight never calls `mmhalow_init`, `mmwlan_boot`, scanning, association, or UDP.
BUSY/WAKE are unwired on the standard WM6180; `HALOW_PS_MODE` must stay disabled.
The driver disables chip power save after radio boot in an RF-enabled build.
The board adapter additionally vetoes transport sleep: this board has WAKE pulled
high and no BUSY wake interrupt. Returning an always-busy indication keeps SPI RX
interrupts enabled; it is not a measurement of the physical BUSY pin. This adapter
is scoped to the RF-enabled experiment and the pinned SDK's no-power-save shim.

## Build and run preflight (PowerShell)

From the repository root:

```powershell
. ./firmware/scripts/enter-idf.ps1
Set-Location firmware/experiments/halow_link
idf.py -B build/ap -D SDKCONFIG=build/ap/sdkconfig -D 'SDKCONFIG_DEFAULTS=sdkconfig.defaults;sdkconfig.ap' build
idf.py -B build/sta -D SDKCONFIG=build/sta/sdkconfig -D 'SDKCONFIG_DEFAULTS=sdkconfig.defaults;sdkconfig.sta' build
```

Identify the current USB ports by ESP32 MAC before flashing. Preserve each device's
existing Flash first; the September 8 inventory already has verified full backups.
After verifying that `RW_LINK_RF_ENABLE` is off in the corresponding generated
`build/<role>/sdkconfig`, flash the selected role with
`idf.py -B build/<role> -p COMx flash`. These partition offsets preserve NVS.
Use `tools/serial_capture.py --reset --until RW_LINK_DONE` from the repository root
to capture a bounded preflight run. The diagnostic firmware remains installed.

## RF-enabled AP / STA test (requires the RF setup)

Do not transmit into an open WM6180 RF connector or connect two RF ports directly
with an unattenuated cable. Follow the project's [RF setup requirements](../../../docs/bringup/xiao-wm6180-first-boot.md).
US country selection describes this module variant; it is not authorization for
radiated operation in Japan. Confirm the applicable operating conditions before
using antennas, or prepare an appropriate conducted/shielded setup.

For each role, use `idf.py -B build/<role> menuconfig`. Under RoadWeave HaLow link
test, enable RF, choose a valid channel and operating class for the test setup,
and configure the same SSID and WPA3 passphrase on both devices. The PSK is blank
by default; keep credentials in ignored generated sdkconfig files, never in Git.
Rebuild after configuration. Changing defaults does not override an existing sdkconfig.
`RW_LINK_TX_POWER_DBM` defaults to a 1 dBm maximum-power override (not a measured
output power). Zero is deliberately excluded because it disables the SDK override.
Both roles restrict operation/scanning to the configured channel from the US
regulatory database; use its S1G operating class.

- AP: static `192.168.50.1/24`, WPA3-SAE, one STA, UDP port 3333, 120-second echo window.
- STA: static `192.168.50.2/24`, waits up to 30 seconds for both association and IPv4 readiness,
  then sends 20 probes. Exact echoed nonce/sequence payloads count as received;
  wrong, stale or duplicate replies do not count.
- Start/reset AP first and wait for `RW_LINK_AP_READY`, then start/reset STA.
- STA reports sent/received counts, mean/max RTT (microseconds), and
  `RW_LINK_RADIO_RESULT=PASS` only for 20/20 exact echoes.
- AP's result covers receiving/echoing at least 20 packets; the STA result is the
  end-to-end measurement. AP stays up for its full window, then shuts down.
- Both stop the radio when their test ends. Socket receives/sends are bounded.
- DHCP, reconnection, long-duration soak and throughput saturation are separate tests.

## Finite continuous validation mode

Enable `RW_LINK_CONTINUOUS` in both RF-enabled builds to run a bounded UDP echo
validation instead of the legacy 20-probe test. Set `RW_LINK_RUN_SECONDS` for each
role (for example AP 240, STA 180), `RW_LINK_PAYLOAD_BYTES` (default 256),
`RW_LINK_INTERVAL_MS` (default 250, STA only), and optionally
`RW_LINK_MAX_PROBES` (0 means use the duration limit). Keep the AP duration long
enough for STA startup and the intended observation. The configured duration is
at most eight hours; this mode does not itself constitute an eight-hour soak.

The AP accepts up to two STAs. Select `RW_LINK_STA_ID=1` for `192.168.50.2/24`
or `RW_LINK_STA_ID=2` for `192.168.50.3/24` when building each STA. Never boot
two STAs with the same ID/IP at once. The AP checks each datagram's source IP
against its ID and reports separate echo counts. These are still static IP
addresses; DHCP requires a separate netif change.

Each run prints `RW_LINK_BOOT`, `RW_LINK_RUN_START`, ten-second cumulative
`RW_LINK_SAMPLE`, per-probe `RW_LINK_ECHO_MATCH` or `RW_LINK_TIMEOUT`, final
`RW_LINK_SUMMARY`, `RW_LINK_RUN_END`, and the existing shutdown/DONE markers.
The STA summary includes planned slots, successful sends, matching replies,
lost sends, skipped slots, send failures, stale/duplicate/invalid replies,
throughput, heap, RSSI, and raw rate-control counters. `offered_bps` counts
successfully sent UDP payload bits over elapsed time; `useful_bps` counts only
matched echoed payload bits. This stop-and-wait workload is a link baseline,
not a maximum-throughput test. RTT percentiles in firmware use 1 ms histogram
bins and round down; `RW_LINK_ECHO_MATCH` carries each exact RTT for host
percentile calculations. Rate-control `rc_sent_start/end` and
`rc_success_start/end` are raw SDK counters, not a retry metric. Continuous
samples use `snr_db=NA` because the wrapper does not expose a validated
continuous SNR measurement. The STA's `RW_LINK_SCAN_TARGET` record includes
raw scan RSSI, scan noise, received-frame bandwidth (`bw_mhz`) and advertised
AP operating bandwidth (`op_bw_mhz`). It computes `scan_snr_db` from the same
scan response only when both dBm inputs lie in -127..-1; otherwise it reports
`NA`. This range check is a conservative bench rule, not an SDK invalid-value
contract or a calibrated SNR guarantee. Scan SNR does not describe later UDP
traffic.
The duplicate counter recognizes another reply to the most recently matched
sequence; older delayed replies count as stale (`late`). A successful
`RW_LINK_RADIO_RESULT` and LED mean the run completed with at least one valid
echo; `RW_LINK_RUN_END quality_gate=host` marks that quality gates are applied
by the host report.

The STA remains enabled across a link drop, letting the pinned Morse supplicant
reconnect. After a previously working link stops answering, the first matching
echo prints `RW_LINK_RECOVERY` with time since detection. It measures application
recovery, which can lag the physical link event. A run with some packet loss can
still report `RW_LINK_RADIO_RESULT=PASS`; use the summary and test-plan thresholds
to judge link quality.

While this mode is active, send a newline-terminated command to the USB
Serial/JTAG console: `RW_LINK_CMD RESTART` acknowledges and performs a software
reset after stopping the AP/STA service and shutting down the MM6108 driver;
`RW_LINK_RESTART_READY` marks completion of that cleanup. Warm boot also clears
the WM6180 SPI IRQ GPIO interrupt before installing the ISR service, because a
still-active module can hold its active-low IRQ across an ESP32 software reset.
`RW_LINK_CMD AP_OFF_10S` on the AP disables its service for ten seconds,
reenables it and emits a new `RW_LINK_AP_READY`; `RW_LINK_CMD STOP` prints the
final summary and shuts down the radio. The AP outage is a controlled service
interruption, not a calibrated RF propagation loss. Software reset is reported
by `RW_LINK_BOOT reset_reason` and must not be counted as a cold power cycle.

### DHCP option

`RW_LINK_DHCP` is an opt-in setting for continuous mode. The AP retains
`192.168.50.1/24` as its server address and provides leases to at most two
associated STAs. Each STA obtains its address, gateway and mask through DHCP;
it logs `RW_LINK_DHCP_LEASE role=STA` with acquisition time, then
`RW_LINK_UDP_BIND` with the address actually used for probes. After link loss,
the STA closes its UDP socket and binds a new one only after another IP event.
There is no fixed-address fallback. The AP logs each lease's MAC/IP pair and
logs `RW_LINK_AP_PEER` when a validated station ID first sends from that lease.
It only echoes a packet when the lease MAC is currently authorized by HaLow.

The pinned Morse wrapper creates a netif with a STA configuration even for AP
mode. This experiment narrowly substitutes DHCP-server and AP-stack flags
during that wrapper's netif creation, keeping the same wrapper-owned RX and
link callbacks. It does not start the ESP32's internal Wi-Fi. Disabling
`RW_LINK_DHCP` retains the earlier fixed-address behavior and legacy test.

## Finite UDP throughput mode

Enable `RW_LINK_THROUGHPUT` alongside `RW_LINK_CONTINUOUS` and
`RW_LINK_DHCP` to replace the echo workload with serial-controlled,
one-way UDP throughput stages. Both roles can send and receive. This mode
uses the same radio, DHCP, IRQ cleanup, and shutdown paths. Its separate
`RW_TPUT_SESSION_SECONDS` deadline defaults to 1800 seconds; a host
`RW_TPUT_CMD STOP` ends it earlier and completes normal radio shutdown.
The earlier `RW_LINK_CMD STOP` is also accepted. The pinned SDK's INFO
logging is reduced to WARN only in throughput builds to avoid per-packet
console work changing the measured rate.

Before `RW_TPUT_READY`, each device prints `RW_LINK_OPERATING_CHANNEL`
with `channel`, `opclass`, `bw_mhz`, `freq_hz`, `pri_bw_mhz`, and
`status=connected`. The class/channel come from the linked VIF; operating
bandwidth and centre frequency come from the matching single-channel
regulatory entry. Primary bandwidth is reported separately and is not used
as operating bandwidth. If the VIF information is unavailable or disagrees
with the selected regulatory entry, the throughput session aborts instead
of reporting an unverified width.

After both devices report `RW_TPUT_READY role=... ip=...`, use the
reported IPs. For each unique, increasing stage ID, first send to the
receiver:

```text
RW_TPUT_CMD ARM stage=1 peer=192.168.50.2 duration_s=30 packet_bytes=1200
```

Wait for `RW_TPUT_RX_READY stage=1`, then send to the sender:

```text
RW_TPUT_CMD SEND stage=1 peer=192.168.50.1 duration_s=30 rate_kbps=1000 packet_bytes=1200
```

`rate_kbps=0` runs unpaced; both device roles support both commands. A
five-second warmup uses a distinct stage ID. After `RW_TPUT_TX_SUMMARY`,
send `RW_TPUT_CMD DRAIN stage=1 sent=<TX summary sent>` to the receiver.
The receiver counts three additional seconds and prints
`RW_TPUT_RX_SUMMARY`. `RW_TPUT_CMD ABORT stage=1` ends a stalled stage.
The host should retain each device's full serial log and require both
session-end, radio-shutdown, and DONE markers.

The maximum `packet_bytes` is 1200 **for the whole UDP datagram**,
including the bench's 16-byte header. The 1184-byte body is checked
byte-for-byte with a deterministic sequence-dependent pattern. A bounded
262144-sequence bitmap counts exact unique packets, duplicates, invalid
payloads, wrong stages/peers, overflow, and out-of-order arrival. The
sender's sequence advances only after a successful `send()`. A one-time
START/ACK precedes data; END/ACK follows it. Control packets never count
as throughput bytes. The receiver counts packets after END separately
as `late_unique`; `drain_unique` is the subset received after the host
DRAIN command. Receiver `active_unique` and `active_body_bytes` describe
the measured window, while `all_unique` includes late delivery for loss
accounting. The host computes goodput over the larger of actual TX
data-phase duration and RX first-to-last active span. Occasional one-tick
yields in the sender/receiver hot loops allow ESP-IDF idle/WDT tasks to run;
this load is part of the reported bench workload.

Each completed stage also emits `RW_TPUT_TX_DIAG` or `RW_TPUT_RX_DIAG` with
the same `stage` ID as its existing summary. These are separate parseable
lines; no existing summary or sample field changes. All durations are
microseconds from `esp_timer_get_time()` and are cumulative for that stage.
`fill_us` measures packet construction over all send attempts. `send_us`
measures time inside data `send()` calls (successful and failed), while
`send_max_us` is their longest call. `send_over_1ms` and `send_over_10ms`
count calls taking at least those thresholds. A long `send()` points to
socket/stack backpressure, but does not isolate radio airtime. `pace_wait_us`
and `pace_waits` count elapsed time and iterations spent yielding before the
next scheduled send in paced mode. `pace_late_us` sums the positive lateness
at each attempted send; `pace_late_max_us` is the largest such lateness.
Both pacing fields remain zero in unpaced mode. Lateness may be caused by
packet construction, `send()`, scheduling, or the deliberate idle yield.
`loop_yield_us` counts elapsed time in the periodic one-tick delay.

On the receiver, `recv_us` and `recv_max_us` measure all `recvfrom()` calls,
including blocking waits; `recv_timeouts` counts EAGAIN/EWOULDBLOCK returns.
`process_us` and `process_max_us` measure elapsed time from the return of
`recvfrom()` through packet classification, payload checks, and bitmap/counter
updates; they also include any START/END acknowledgement or error log in that
iteration. `verify_us` is a subset of `process_us`.
`verify_us`, `verify_max_us`, and `verify_packets` measure the payload-byte
check for in-range, stage-matched data packets, including failed checks and
duplicates. They exclude socket receive, header checks, and bitmap updates.
The timer reads and counter updates add a small cost to each packet. These
durations can overlap the stage wall-clock span conceptually (for example,
`send_us` includes OS scheduling while in `send()`) and should not be added
to infer CPU utilization. Control-packet exchanges, samples, and final log
flushing are outside the data-path counters. The detailed lines are emitted
only after the stage, so serial logging does not occur on each packet.

This measures observed, verified UDP goodput for the chosen channel,
bandwidth, placement, hardware, and stage settings. It does not by itself
measure a theoretical PHY maximum or sustained TCP application throughput.

## User LED

The [XIAO ESP32S3 user LED](https://wiki.seeedstudio.com/xiao-esp32s3-freertos/)
uses GPIO21, active low, separate from the HaLow SPI pins.

| Pattern | Meaning |
|---|---|
| Slow blink (500 ms on / 500 ms off) | Starting or waiting for a peer |
| On | STA connected / AP has an authorized STA |
| Brief off pulse (80 ms) | A valid UDP echo was received/sent |
| Two flashes every 2 seconds | Test completed successfully; radio stopped |
| Three flashes every 1.6 seconds | Test failed; inspect serial log |

The final pattern remains until reset. In preflight mode, the result pattern
describes preflight only; it does not indicate a radio connection.
Resetting an RF-enabled build starts another test automatically.

## Current validation status

The September 19 retest established HaLow association and UDP echo after correcting
channel setup ordering, vetoing transport sleep on the unwired-BUSY board, and
providing the lwIP transmit-wrap callback alongside explicit TX VIF selection.
See the [retest record](../../../docs/bringup/halow-link-retest-2026-09-19.md) for
the tested device pairs, results and remaining limits. Earlier failed RF attempts
remain in the [September 8 record](../../../docs/bringup/halow-link-antenna-test-2026-09-08.md).
The experiment is separate from production firmware. Preflight success is recorded
[separately](../../../docs/bringup/halow-link-preflight-2026-09-08.md).

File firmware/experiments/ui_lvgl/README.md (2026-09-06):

# ui_lvgl

2.8 インチ ILI9341（SPI）+ XPT2046 タッチ + LVGL 9 の UI 先行実装（`docs/display-selection.md`）。
GROUP（誰が話しているか）/ RADAR（heading-up）/ CONVOY（前後距離）の 3 画面と、下段の MUTE / PTT（長押し）/ NEXT ボタン。
`RW_UI_SIMULATE=y` なら GPS も無線もなしで 3 台の隊列が動くので、ディスプレイが届けばそのまま見た目を詰められる。

**Windowsで画面確認する場合**はRepoルートから `.\firmware\scripts\ui-sim.ps1` を実行する。
実機と同じ画面コードをSDLウィンドウで描画し、マウス操作・模擬状態の切替・PNG保存・自動画像比較に対応。
テストは `.\firmware\scripts\ui-sim.ps1 -Action Test`。
操作方法・基準画像の更新手順は [PCシミュレーター](pc/README.md) を参照。

```bash
cd firmware/experiments/ui_lvgl
idf.py set-target esp32s3
idf.py menuconfig    # RoadWeave UI: LCD/touch pins, SPI MHz
idf.py -p /dev/cu.usbmodemXXXX flash monitor
```

既定ピンは WM6180 と同じ側面ピン（SCLK=D8/GPIO7、MOSI=D10/GPIO9、MISO=D9/GPIO8、CS=D3/GPIO4、DC=D2/GPIO3、RST=D1/GPIO2、BL=D0/GPIO1、T_CS=D4/GPIO5）。
**HaLow モジュールを載せた XIAO では使えない**（ピン競合）。UI 単体の検証用。Rev.A では LCD を別 SPI（AUX_SPI）に置く。

画面の設計ルール: 一目で読める大きな文字、深いメニューなし、走行中はボタン 3 つだけ。位置の古い peer は `?`（3 s）/ `x`（10 s）で示し、
距離を確定表示しない（`docs/gps-and-maps.md` §2）。

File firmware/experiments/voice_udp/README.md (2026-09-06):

# voice_udp

HaLow 到着前に、XIAO の内蔵 2.4 GHz Wi-Fi を代役にして音声パイプラインを end-to-end で通す実験。
I2S mic → HPF → IMA-ADPCM → RWP/0.1 VOICE → UDP → (Mac) → UDP → jitter buffer → decode → I2S amp。
Morse component も lwIP の netif を提供するので、HaLow 到着後は socket 部分をそのまま流用できる。

## 使い方

**先に XIAO の U.FL に 2.4 GHz アンテナを付ける。** アンテナなしでは数十秒でリンクが崩れ、PA にも負荷がかかる（[2026-09-06 計測](../../../docs/bringup/voice-udp-2026-09-06.md)）。

```bash
cd firmware/experiments/voice_udp
idf.py set-target esp32s3
idf.py menuconfig      # RoadWeave voice_udp: Wi-Fi SSID/pass, peer IP (Mac), pins
idf.py -p /dev/cu.usbmodemXXXX flash monitor
```

Mac 側（別ターミナル）:

```bash
python3 tools/rwp_peer.py echo            # 往復させて RTT と mouth-to-ear を node 側に表示
python3 tools/rwp_peer.py record mic.wav  # mic の音を Mac に WAV で保存（amp 不要でマイク品質を確認）
python3 tools/rwp_peer.py send voice.wav --to <node ip>   # Mac から node の speaker へ
```

node の 1 秒ごとの出力例:

```
tx 50 rx 50 bad 0 | echo 50 rtt avg 6 max 14 ms | mouth-to-ear ~88 ms | jb depth 40 played 48 gap 0 late 0 underrun 1
```

`mouth-to-ear` は capture → encode → UDP 往復 → jitter buffer → decode → I2S 書き込みまで。
スピーカーの実音までは I2S DMA 分（約 20〜40 ms）を足す。SSID/パスワードは `sdkconfig`（git 管理外）にだけ入る。

## Windows PowerShell

Repoルートから`. .\firmware\scripts\enter-idf.ps1`で専用環境を起動できる。
`RW_PEER_IP`にはWindowsのLAN IPv4を設定する。Windowsは有線LANでもよく、ESP32の2.4 GHz Wi-Fiから到達できることが条件。

```powershell
idf.py -C firmware/experiments/voice_udp menuconfig
idf.py -C firmware/experiments/voice_udp -p COM4 flash
```

別ターミナルで環境を起動し、peerを動かす:

```powershell
python tools/rwp_peer.py echo --duration 90
```

peer実行中に元のターミナルでログを採る:

```powershell
python tools/serial_capture.py --port COM4 --reset --seconds 75 --output .private/windows-bench/voice.log
```

`--duration`はecho/recordを指定秒で終了する。無受信でも終了し、recordのWAV headerを確定する。
`--bind <Windows LAN IPv4>`で待受interfaceを指定できる。既定は全IPv4 interface。
echoはADPCM/Opusの両方に対応し、record/sendのcodecはADPCMのみ。
`--duration`で終了するのはPC側peerだけで、ESP32の送信は停止しない。試験後は`firmware/`のsmoke firmwareへ書き戻す。

Windows Firewallの限定ルール、アンテナ条件、ビルド検証結果は[Windowsベンチ手順](../../../docs/bringup/windows-bench-2026-09-06.md)を参照。
Windowsとの実機UDP往復を確認した[2026-09-06の無線試験結果](../../../docs/bringup/windows-wifi-2026-09-06.md)も参照。

## モード（menuconfig "RoadWeave voice_udp"）

| 設定 | 意味 |
|---|---|
| `RW_COORDINATOR=y` | この node が Group Coordinator（floor 管理）。Mac echo のベンチでは y のまま（自分で自分に grant） |
| `RW_COORDINATOR=n` + `RW_COORD_IP` | 別の node が coordinator。REQUEST/RENEW/END を UDP で送り、GRANT/DENY を待つ |
| `RW_GROUP_BROADCAST=y` | voice を IPv4 broadcast へ送る（同じ AP 上の 2 台以上） |
| `RW_TX_ALWAYS=y` | PTT を押しっぱなしとみなす（ベンチ用。120 s ごとに END → 再要求が入る） |
| `RW_PLAY_ECHO=y` | 自分の sender_id のフレームも再生（Mac echo で自分の声を聞く） |

2 台構成の例: node A `COORDINATOR=y, BROADCAST=y`、node B `COORDINATOR=n, COORD_IP=<A の IP>, BROADCAST=y`。

実装済み: floor control（`components/rwp/floor.h`、BUSY_WAIT 再要求含む）、TX 中の speaker hard mute、
簡易 PLC（gap で直前フレームを -6 dB ずつ最大 3 frame 繰り返し）。1 秒ごとの行に floor 状態と grant/busy/fail 数が出る。

## 未実装（P0-B 本実装で入れる）

- targeted PTT（NODE / SUBGROUP 宛）と application 暗号化
- PC側のOpus WAV record/send（node側の`RW_CODEC_OPUS`は実装済み）

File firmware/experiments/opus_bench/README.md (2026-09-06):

# opus_bench

ESP32-S3 上で Opus encode/decode の CPU 時間と heap を計測する（Issue #14）。

```bash
firmware/components/opus/fetch-upstream.sh
cd firmware/experiments/opus_bench
idf.py set-target esp32s3
idf.py -p /dev/cu.usbmodemXXXX flash monitor
```

`=== OPUS_BENCH_DONE ===` まで約 30 秒。結果は [docs/bringup/opus-bench-2026-09-05.md](../../../docs/bringup/opus-bench-2026-09-05.md)。

Windows PowerShell（Repoルートから）:

```powershell
. .\firmware\scripts\enter-idf.ps1
.\firmware\components\opus\fetch-upstream.ps1
idf.py -C firmware/experiments/opus_bench -D IDF_TARGET=esp32s3 build
idf.py -C firmware/experiments/opus_bench -p COM4 flash
python tools/serial_capture.py --port COM4 --reset --seconds 90 --until OPUS_BENCH_DONE --output .private/windows-bench/opus.log
```

`COM4`は2026-09-06の実機port。[Windows実測結果](../../../docs/bringup/windows-bench-2026-09-06.md)。

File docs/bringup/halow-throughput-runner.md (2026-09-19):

# Bounded HaLow UDP throughput runner

`tools/halow_throughput_run.py` captures one direction and one channel width per
run. It uses COM4/AP with COM5/STA, checks both native USB serial identities,
starts the AP before the STA, and requires each role's managed throughput
session and the STA's fresh DHCP lease. The 1200-byte UDP datagram contains a
16-byte test header and 1184 bytes of checked application body. The program
never switches radios or channel width; flash the corresponding AP and STA
binaries before each width's captures.

Run it from this repository so `host_git` records the host tool revision. The
binary paths must name the actual flashed images. Use a new output directory
under `.private` for every invocation:

```powershell
& D:/Espressif/tools/python_env/idf5.4_py3.12_env/Scripts/python.exe -B tools/halow_throughput_run.py `
  --direction sta_to_ap --bandwidth-mhz 1 --sta COM5 `
  --ap-bin D:/RoadWeave/.private/halow-throughput-20260919/firmware-41929f5/tput-1mhz-ap.bin `
  --sta-bin D:/RoadWeave/.private/halow-throughput-20260919/firmware-41929f5/tput-1mhz-sta.bin `
  --fw-source-commit 41929f545b5ca70e434363f7edc0d84584270669 `
  --output-dir D:/RoadWeave/.private/halow-throughput-20260919/1mhz-sta-to-ap
```

For the reverse direction, pass `--direction ap_to_sta` and a fresh output
directory. Repeat both directions with the 2 MHz binaries and
`--bandwidth-mhz 2`. For a future 4 or 8 MHz run, also provide an explicit
positive `--channel` and `--opclass` selected from the pinned SDK's regulatory
table and verified for the module and test location. Before the first UDP
stage, the runner requires each radio's current-boot `RW_LINK_CHANNEL`
(selected frequency, width, successful status), `RW_LINK_RADIO_CONFIG`
(country, channel, class), and `RW_LINK_OPERATING_CHANNEL` (post-association
frequency, channel, class, operating width, `status=connected`). Both sides
must match the requested profile and country. Firmware without the operating
channel marker cannot produce a passing 4/8 MHz run. A selected channel or
STA scan target alone is insufficient evidence of
the associated width. The runner records verified profile evidence in
`report.json`; missing or conflicting evidence fails before load begins.
Legacy 1/2 MHz invocations retain their previous evidence requirements.

The firmware has a 262144-packet sequence bitmap per stage. The host rejects
paced rate/duration combinations that would fill it. A 4/8 MHz full run also
caps the unpaced saturation observation at 30 seconds; this bounds that
observation and does not turn a bitmap limit into an RF performance result.

The default finite policy warms up for 5 seconds, tests
128/256/512/1000/2000/4000/8000 kbit/s for 1/2 MHz, then extends the
4 MHz search to 12000/16000 kbit/s and the 8 MHz search to
12000/16000/24000/32000 kbit/s. It runs 30 seconds per search stage. The
1/2 MHz legacy search stops at its first quality failure; the 4/8 MHz search
checks the complete fixed grid so isolated low-load loss cannot hide a higher
passing rate. It refines the boundary above the highest passing grid point
with two midpoint tests, attempts three
60-second confirmations at the highest candidate and lower candidates if
needed, then runs one unpaced saturation observation. The host caps its
session at 1500 seconds; the firmware session watchdog is 1800 seconds.
`--smoke --rates-kbps 128 --warmup-seconds 5 --stage-seconds 5
--repeat-seconds 5 --max-seconds 180` checks the protocol without unpaced
load and reports `SMOKE_PASS` instead of a full throughput result.

Every stage ARM's the receiver before SEND. The host waits for the TX summary,
then commands a three-second receiver DRAIN with the exact TX successful-send
count. It checks both summaries, START/END acknowledgments, device-clock DATA
duration, receiver span, active and final unique delivery, packet/body byte
counts, and the END/DRAIN count. Invalid payload, wrong stage/peer, sequence
overflow, premature abort, missing marker, serial panic, unexpected boot or
STA disconnect invalidates the capture. Duplicates, out-of-order arrivals,
send failures and tail packets are reported separately; they do not inflate
unique bytes. A paced candidate needs at least 99% active **and** final
delivery, actual TX rate at least 95% of target, and a DATA window at least
99% of requested duration. The unpaced result is an observation only.

The report's active UDP and body goodput use the larger of actual TX DATA
duration and the receiver's first-to-last active unique span. The highest
three-repeat passing target and its body goodput remain separate from the
unpaced saturation result. A passed upper search limit is labeled as a search
ceiling; no result is a PHY maximum or proof of long-term capacity.

Private `ap-raw.log` and `sta-raw.log` retain complete serial data. The
incremental `events.jsonl` retains host commands and stage timestamps even if
interrupted. `report.json` and `report.md` include every search stage,
confirmation, failure and binary SHA256; the optional `--public-log` copies
only allowlisted firmware fields. Both devices must acknowledge STOP and emit
session-end, radio-shutdown, radio-result PASS, and DONE markers before the
capture can pass.

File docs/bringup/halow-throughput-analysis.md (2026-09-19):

# Offline HaLow throughput analysis

`tools/halow_throughput_analyze.py` compares saved `report.json` files or the
published `metrics.json` bundle without serial hardware:

```powershell
python tools/halow_throughput_analyze.py .private/run-a/report.json .private/run-b/report.json --output .private/comparison.json
python tools/halow_throughput_analyze.py docs/bringup/logs/2026-09-19-throughput/metrics.json --events-dir docs/bringup/logs/2026-09-19-throughput
```

The JSON output gives each stage's target and actual TX rates, active and final
delivery, body goodput, and diagnostic flags. It reports the highest valid,
non-warmup observed goodput from a completed full case separately from the
three-repeat confirmed target; neither is a hardware ceiling. `--events-dir`
recomputes complete saved stage evidence from `CASE.events.jsonl` using the
runner's assessor and reports any discrepancy, including changed counters or
peer addresses. Adjacent comparison deltas require the same direction, width,
firmware source, and both binary hashes. Missing provenance blocks comparison.

A first failed search stage is never treated as a capacity bound: low-load loss
and confirmation variability may be nonmonotonic. Width is host metadata in
these reports; the captured events do not independently verify channel or
operating class.

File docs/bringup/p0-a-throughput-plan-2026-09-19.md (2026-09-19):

# HaLow最大UDP転送速度の実証計画 — 2026-09-19

目的は、低負荷のstop-and-wait echoから進み、現在のESP32-S3＋SPI＋Wio-WM6180経路で受信できる最大転送速度を実測すること。計画・管理・独立レビューはAstra、実装はSol、実機操作は主担当が行う。

既存の[有限通信実証](p0-a-validation-report-2026-09-19.md)を保存したmain `d6bb978496d232f0bc813e0e0c7d5486a1a29215`から機能別branchを作る。長時間運転、電源断反復、測定器の必要な試験は今回も対象外。

## 測る値

1. **最高合格負荷:** 受信率99%以上、送信実績が目標の95%以上、60秒の反復3回すべてで成立した最高の検査済み送信負荷。受信側unique bytesによるgoodputの各回・範囲も示す。
2. **飽和時の最大観測受信速度:** 無制限または合格上限を超える送信負荷で観測した最大receiver goodput。損失・送信失敗を併記し、上記の合格負荷と区別する。

検査点の間隔と有限時間に制約される実測上限であり、PHYの理論最大速度や長時間持続能力とは呼ばない。速度の単位はbit/s（十進）とし、1200 BのUDP payload全体と、試験headerを除くapplication bodyを区別する。UDP/IP/MACのheader、再送、ackはpayload goodputに含めない。

## 条件と比較

| 条件 | 固定する内容 |
|---|---|
| 機器 | COM4 AP、COM5 STA1。COM6は無線停止状態を維持 |
| 通信経路 | ESP32-S3→SPI→MM6108→HaLowのみ。内蔵Wi-Fi不使用 |
| SPI／console | SDK設定40 MHz。actual clockはログで確認できた場合に別記。consoleはnative USB Serial/JTAG |
| RF | 既確認の使用場所、装着済みアンテナ、設定上限1 dBmを継続 |
| 幅と周波数 | 1 MHz/ch3/opclass1/903.5 MHz、2 MHz/ch6/opclass2/905 MHz |
| 方向 | STA→APとAP→STAを別々に測る。同時双方向にしない |
| IP | 既存の検証済みDHCP、leaseとUDP bindを確認してから測定 |
| UDP | 1200 B payload、echo待ちなしの片方向stream。packet単位のUART出力なし |
| 時間 | 初期warmup5秒、探索30秒、確認60秒×3。各stage終了後3秒以上drain。方向ごとにsessionを分け、必要ならglobal watchdogを1800秒へ設定 |
| 記録 | source/binary SHA256、実測duration、rate、全counter、起動・lease・正常停止を保存 |

中心周波数も変わり、周囲雑音・物理配置を実験室で固定できていないため、差を帯域幅だけの効果としない。受信goodputはCPU・lwIP・SPI・無線・受信検証処理を含む今回の経路の性能である。

## 実装契約

既存AP/STA初期化、DHCP adapter、起動IRQ対策、正常無線停止を再利用し、独立したthroughput modeを追加する。従来のecho modeを維持する。hostから受信側をARMし、確認後に送信側をSTARTする。stage IDは毎回変え、別stageや旧packetを加算しない。両端の最終counterは無線に依存しないUSB serialで取得する。

- UDP headerは16 B、magic、version、stage ID、sequence等を持ち、残り1184 Bを決定的なbodyとして検査する。byte orderはFWで明示し、hostのsummaryにheader bytesを記録する。最大262144 sequenceのbitmapは32 KiBで、上限超過は無効。
- sequenceは送信成功したdatagramに対して連番とする。attempt、send error、予定負荷からのskippedは別counter。send成功だけで受信成功を判断しない。
- 受信側はstageごとのbounded bitmap等でunique sequenceを判定し、duplicate、out-of-order、invalid、範囲外を別記する。最大sequenceから受信数を推定しない。overflowはstage無効とする。
- rate制御は単調時計を用い、処理遅延後に無制限のcatch-up burstを出さない。目標rateと実際の送信bytes/timeをともに出力する。rate0などで有限時間の飽和送信も可能にする。
- 1秒程度の集計sampleと最終summaryのみを出し、packet単位printfやUSBの転送速度を測定の律速にしない。throughput設定だけSDKログをINFOからWARNへ下げ、その設定を記録する。終端marker欠落やconsole write timeoutを成功としない。
- TX終了後もRXを3秒以上維持してqueueをdrainする。late/tail、receiverの最初・最後の受信時刻とspanを記録し、前stageの残留を次へ混ぜない。
- packet lossはhostで `(TX成功数−RX unique数)/TX成功数` として計算する。TX失敗率も別記。RX uniqueがTX成功数を超えた場合は集計不整合で無効。
- 主goodputの分母は、実際のTX測定時間とRX first→last spanの大きい方とする。短いfirst→last窓による過大評価を避け、drainで長く残ったbacklogの影響を隠さない。1秒sampleとtailを併読し、一瞬のpeakを持続値にしない。
- warmupは別stage、または明示phaseで分離する。省略・混入を避け、送受信counterの同じ測定範囲を保証する。
- bounded stage・idle watchdog・host STOPで終了可能にする。終了時は両端のSTOP ACK、radio shutdown、DONEまで確認する。

実装前に合意した制御は `RW_TPUT_CMD ARM stage=N duration_s=...`、`SEND stage=N peer=... duration_s=... rate_kbps=... payload_bytes=1200`、`DRAIN stage=N sent=N` とし、telemetryを `RW_TPUT_*` に分離する。RX_READY後にsenderがSTART制御packetを送り、ACKを得てからdata測定窓を開始する。ENDには成功送信総数を持たせ、ACKを最大3秒再試行する。host DRAINはEND喪失時もsummaryを回収するが、ENDなしは有効測定にしない。

END前のactive uniqueを主goodputへ使い、END後の新規受信はtailとして分ける。最終deliveryは両方を含めるが、最高合格負荷にはactive deliveryも99%以上を要求する。大量のqueueをdrainで受け切っただけの状態を持続合格にしない。DATA窓が指定時間の99%未満の場合やabort時は無効。送信処理の実際の延長時間も記録する。

既存SDKには `morsemicro__halow/examples/iperf` のUDP/TCP REPL例があり、`espressif/iperf-cmd ~0.1.3`へ依存する。ただしSTA接続用の独立例で、今回のAP/DHCP/board対策を含む完成済みbenchの代替ではない。MorseのUDP server実装も受信時刻・out-of-sequenceを扱う参考になるが、そのfirst/last durationだけで今回の合格値を定義しない。TCPは接続経路と正確な受信計数を低コストで再利用できる場合の追加項目とし、UDP実測を先に完了する。

## 実行順と判定

各幅・方向の4条件で同じ手順を用いる。

1. 初期化・DHCPを確認し、warmup5秒を行う。最初に低負荷でpacketの計数一致を確認する。
2. 30秒stageで128、256、512 kbit/s、1、2、4、8 Mbit/sと増やす。99%受信または目標rateの95%追随を満たさない最初の点を得たら、低損失境界の探索を止める。
3. 最後の合格点と最初の不合格点の間を2段階の中間rateで絞る。最低rateから失敗した場合は低rateへ下げ、上限8 Mbit/sまで合格した場合は無制限stageの実績から追加rateを決める。
4. 境界候補を60秒×3回測定する。3回すべてactive/final受信率99%以上・送信追随95%以上、予期しないreset、lease消失、invalid、計数不整合、buffer overflowなしを合格条件とする。1回でも満たさなければ候補を下げて確認し、変動も残す。
5. 別の有限飽和stageを1回実施する。過負荷を承知で測る観測点としてlossを報告し、探索や反復の失敗を隠すためには使わない。
6. 両端を正常停止してから方向／幅を変える。すべて終わったら全3台の現在状態と、再起動した時に開始するFWの挙動を記録する。

送信側が目標を生成できない場合は「RF受信上限」と断定せず、今回の送信path上限として実際のrateを報告する。上限まで不合格点が得られなければ「少なくともこの実測値」であり、最大を確定したとはしない。

## Branchと保存

| Branch | 担当・内容 | 確認 |
|---|---|---|
| `codex/halow-throughput-plan` | Astra: 計画・計測定義 | 実行前に条件・判定を固定 |
| throughput firmware feature | Sol: 有限stream送受信・counter・制御 | 両role/両幅build、既存mode維持、bounded終了 |
| throughput host tools feature | Sol: ARM/START/drain・集計・探索 | 正常／loss／duplicate／epoch混入／rate未達／途中終了のoffline検査 |
| throughput results | Astra: 実測表・安全に抽出したログ・残件 | binary対応、raw hash、最高合格値と飽和値、全失敗点を保持 |

実機に合わせた実装schema・上限・探索点の調整は実行前に記録する。結果は幅×方向、送信目標と実績、RX payload/body goodput、loss、duration、反復範囲を一覧にし、秘密設定を含めない。過去の約82 kbit/s固定負荷の結果を最大速度として転用しない。

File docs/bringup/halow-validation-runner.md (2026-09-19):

# Finite HaLow serial validation runner

`tools/halow_validation_run.py` captures COM4 AP with COM5 STA, COM6 STA, or
both stations through the ESP32-S3 native USB serial ports. It supports the
continuous MM6108 SPI HaLow validation firmware, not the older one-shot
20-probe image. Three-node mode requires STA IDs 1 and 2, distinct addresses,
and AP capacity for two stations. The optional `--sta2 COM6` selects it;
without that flag the established two-node path is unchanged.

Use the ESP-IDF Python environment with `pyserial` and `esp_idf_monitor` installed.
Before a hardware run, build/flash AP and selected STAs with matching SSID/PSK in local
ignored sdkconfig. Select continuous mode, a finite firmware run duration longer
than the host observation, and the intended channel width. For the baseline,
use 256-byte probes at 250 ms, observe at least 120 s, and leave room for the
runner's STOP command. The baseline discards the first 10 s using the first
sample at or after that point, then requires 120 s of observation and 200 sent
probes. Keep the PSK and complete raw logs under `.private`.

Three-node baseline example (STA ID 1 on COM5, STA ID 2 on COM6):

```powershell
& D:/Espressif/tools/python_env/idf5.4_py3.12_env/Scripts/python.exe tools/halow_validation_run.py `
  --sta COM5 --sta2 COM6 --seconds 150 `
  --output-dir .private/halow-validation/three-node-baseline `
  --ap-bin firmware/experiments/halow_link/build/ap/roadweave_halow_link.bin `
  --sta-bin firmware/experiments/halow_link/build/sta/roadweave_halow_link.bin `
  --sta2-bin firmware/experiments/halow_link/build/sta2/roadweave_halow_link.bin
```

Both station reports need at least 200 successful sends and 99% exact echoes
after the first 10 s, plus a common 120 s measurement window with at least
200 exact echoes from each station. The AP's `echo_id1` and `echo_id2` counts
must cover every exact reply during the AP's final run, including replies
before a station restart. For DHCP builds the analyzer
uses each station's lease and UDP bind address, checks they differ, and checks
the AP's peer ID/address mapping. DHCP evidence must come from the current
boot; software resets require fresh lease/bind evidence. The report identifies
static or DHCP mode.

```powershell
& D:/Espressif/tools/python_env/idf5.4_py3.12_env/Scripts/python.exe tools/halow_validation_run.py `
  --sta COM5 --seconds 150 `
  --output-dir .private/halow-validation/com5-width1-run1 `
  --ap-bin firmware/experiments/halow_link/build/ap/roadweave_halow_link.bin `
  --sta-bin firmware/experiments/halow_link/build/sta/roadweave_halow_link.bin `
  --public-log docs/bringup/logs/com5-width1-run1.log
```

The runner verifies the selected USB serial-number MAC against the known COM4,
COM5 and COM6 inventory. It holds DTR/RTS deasserted, applies an initial ESP-IDF
serial reset to AP, waits for a fresh `RW_LINK_AP_READY`, and only then resets
the selected stations. That serial reset is **not** a physical cold boot. `--no-initial-reset`
is available when the firmware is already running, but a fresh AP_READY still
must be captured. No USB serial tool can establish the 50 physical power-cycle
criterion; record those cycles separately with a controlled power fixture.

To exercise faults, repeat `--fault ROLE:ACTION:OFFSET_SECONDS` within a
bounded host run. Available actions are `software_reset` for either role and
`ap_off_10s` for AP. For example, three AP software resets:

```powershell
& D:/Espressif/tools/python_env/idf5.4_py3.12_env/Scripts/python.exe tools/halow_validation_run.py `
  --sta COM5 --seconds 240 `
  --fault ap:software_reset:30 --fault ap:software_reset:90 --fault ap:software_reset:150 `
  --output-dir .private/halow-validation/com5-ap-reset
```

Run STA resets and `ap_off_10s` in separate captures, using three offsets each.
In three-node mode, `--fault sta:software_reset:30` or
`--fault sta2:software_reset:30` resets one station. The other station must
keep producing exact echoes during the restart, with no outage marker and no
inter-echo gap over 5 s across that window. The restarted station must resume
within 60 s of its new boot and record 20 consecutive exact echoes.
Keep both firmware role durations longer than the observation plus any restart
delay. At the host deadline the runner sends `RW_LINK_CMD STOP` to active roles
and waits up to 20 s for final `RW_LINK_SUMMARY`, radio result, radio shutdown,
and `RW_LINK_DONE`. A timeout or interrupted capture fails. The command's ACK,
new boot marker, AP_READY, valid echoes, recovery windows, and heap samples are
saved with host UTC and monotonic timestamps. After each fault, the acceptance
check requires a valid echo within 60 s of the AP_READY or STA boot and 20
consecutive exact echoes. The baseline needs at least 200 successfully sent
probes, at least 99% exact echoes among them, and at least 120 s observed from
the first sample after the 10 s warmup to summary. The one-second probe timeout and skipped probes are
reported separately from successfully sent probes.

Each private output directory contains `ap-raw.log`, `sta-raw.log`, and, in
three-node mode, `sta2-raw.log`, plus
`events.jsonl`, `report.json`, and `report.md`. The raw logs preserve driver
warnings. The JSON report counts `Address base set failed` and `Unknown TLV`
by role, boot index and raw line; the former is a propagated transport error,
while the latter is skipped during TLV parsing. Review their local context
before classifying either. The optional public log includes allowlisted
`RW_LINK_*` fields only and removes PSK/SSID. Check it before committing.
Serial command writes time out after 2 s. `events.jsonl` is flushed after each
event, so a forced termination still leaves host fault times and parsed serial
evidence; an ACK that was not finalized may remain conservatively unacknowledged.
An interrupted run without final summaries, shutdown markers, and `RW_LINK_DONE`
cannot pass even if its raw logs contain echoes.
Scan-time SNR is retained only when firmware reports valid RSSI and noise.
`NA` stays unknown, and negative SNR is preserved. The UDP summary's
`snr_db=NA` is not replaced with the scan-time value.

For offline reanalysis of an event file:

```powershell
& D:/Espressif/tools/python_env/idf5.4_py3.12_env/Scripts/python.exe tools/halow_validation.py `
  .private/halow-validation/com5-width1-run1/events.jsonl `
  --json .private/halow-validation/com5-width1-run1/reanalysis.json `
  --markdown .private/halow-validation/com5-width1-run1/reanalysis.md
```

Offline parser tests require no serial device:

```powershell
& D:/Espressif/tools/python_env/idf5.4_py3.12_env/Scripts/python.exe -m unittest discover -s tools/tests -p test_halow_validation.py
```

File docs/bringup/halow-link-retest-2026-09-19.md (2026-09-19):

# HaLow SPI・無線通信再試験（2026-09-19）

**3台ともSPI診断PASS。COM4をAPにして、COM5・COM6を順番にSTAとして接続し、
両組ともUDP 20/20往復に成功した。** 3台同時通信の試験ではない。
通信にはSPI接続のMM6108だけを使用し、ESP32内蔵2.4 GHz Wi-Fiを初期化していない。
一般的な2.4/5 GHz WLANは使わない方針をユーザーと再確認した。

## 機器・条件

| ポート | ESP32 MAC | 今回の役割 |
|---|---|---|
| COM4 | 44:b1:76:b0:57:20 | AP、192.168.50.1/24 |
| COM5 | 44:b1:76:b0:57:1c | 1組目のSTA、192.168.50.2/24 |
| COM6 | 44:b1:76:ae:c4:90 | 2組目のSTA、192.168.50.2/24 |
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

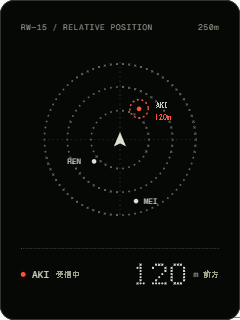
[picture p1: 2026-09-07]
firmware/experiments/ui_lvgl/pc/reference/web-dot15.png

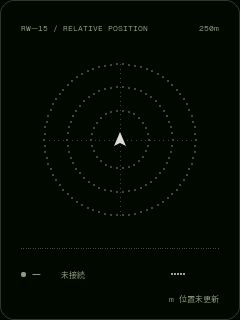
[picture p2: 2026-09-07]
firmware/experiments/ui_lvgl/pc/baselines/dot_offline.png

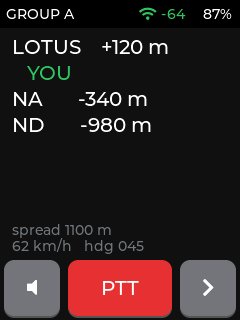
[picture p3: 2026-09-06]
firmware/experiments/ui_lvgl/pc/baselines/convoy.png

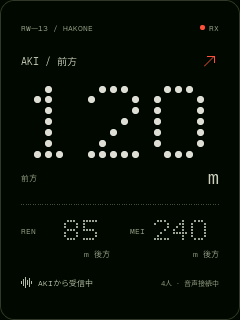
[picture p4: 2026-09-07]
firmware/experiments/ui_lvgl/pc/baselines/dot13.png

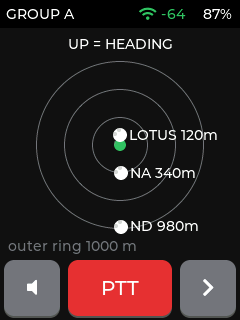
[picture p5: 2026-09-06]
firmware/experiments/ui_lvgl/pc/baselines/radar.png

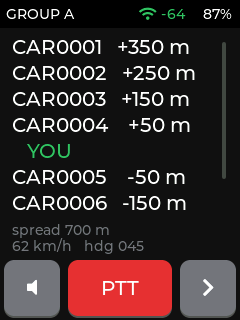
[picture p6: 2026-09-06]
firmware/experiments/ui_lvgl/pc/baselines/max_convoy.png

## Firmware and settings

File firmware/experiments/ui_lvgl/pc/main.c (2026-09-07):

#include <stdio.h>
#include <stdlib.h>
#include <string.h>
#include <ctype.h>
#include <SDL.h>
#include "lvgl.h"
#include "scenarios.h"
#include "capture.h"
#include "ui_dot.h"

static bool quit_requested, pause_requested, reset_requested, save_requested, step_requested;
static int requested_screen = -1, requested_zoom;
static const char *requested_scenario;
static bool trace_input;
static bool printable_down[128];
static bool zoom_cycle_requested;

/* SDL event watches may run on another thread: this watch only handles events
 * originating in the main thread's SDL_PollEvent, and queues UI work for later. */
static SDL_threadID main_thread;
static int SDLCALL event_watch(void *unused, SDL_Event *event)
{
    (void)unused;
    if (trace_input && (event->type == SDL_KEYDOWN || event->type == SDL_KEYUP || event->type == SDL_TEXTINPUT)) {
        if (event->type == SDL_TEXTINPUT) printf("SDL text: %s\n", event->text.text);
        else printf("SDL key type=%u thread=%lu main=%lu key=%d repeat=%d\n", event->type,
                    SDL_ThreadID(), main_thread, event->key.keysym.sym, event->key.repeat);
        fflush(stdout);
    }
    if (SDL_ThreadID() != main_thread) return 1;
    if (event->type == SDL_QUIT ||
        (event->type == SDL_WINDOWEVENT && event->window.event == SDL_WINDOWEVENT_CLOSE))
        quit_requested = true;
    if (event->type == SDL_WINDOWEVENT && (event->window.event == SDL_WINDOWEVENT_FOCUS_LOST ||
        event->window.event == SDL_WINDOWEVENT_LEAVE))
        { memset(printable_down, 0, sizeof(printable_down)); ui_dot_cancel_touch(); }
    SDL_Keycode key;
    if (event->type == SDL_TEXTINPUT) {
        /* Accessibility / remote input can supply WM_CHAR without a physical
         * scan code. Accept single ASCII shortcuts, but suppress the text that
         * follows a regular keydown so Space does not toggle twice. */
        unsigned char c = (unsigned char)event->text.text[0];
        if (c >= 128 || c == 0 || event->text.text[1] != '\0') return 1;
        key = tolower(c);
        if (printable_down[key]) return 1;
    } else if (event->type == SDL_KEYDOWN || event->type == SDL_KEYUP) {
        key = event->key.keysym.sym;
        if (key >= 0 && key < 128) {
            key = tolower((unsigned char)key);
            printable_down[key] = event->type == SDL_KEYDOWN;
        }
        if (event->type == SDL_KEYUP || event->key.repeat) return 1;
    } else return 1;
    switch (key) {
        case SDLK_ESCAPE: quit_requested = true; break;
        case SDLK_SPACE: pause_requested = true; break;
        case SDLK_r: reset_requested = true; break;
        case SDLK_s: save_requested = true; break;
        case SDLK_PERIOD: step_requested = true; break;
        case SDLK_1: requested_screen = UI_SCREEN_GROUP; break;
        case SDLK_2: requested_screen = UI_SCREEN_RADAR; break;
        case SDLK_3: requested_screen = UI_SCREEN_CONVOY; break;
        case SDLK_4: requested_scenario = "dot13"; break;
        case SDLK_5: requested_scenario = "dot14"; break;
        case SDLK_6: requested_scenario = "dot15"; break;
        case SDLK_7: requested_scenario = "dot16"; break;
        case SDLK_F1: requested_zoom = 1; break;
        case SDLK_F2: requested_zoom = 2; break;
        case SDLK_F3: requested_zoom = 3; break;
        case SDLK_z: zoom_cycle_requested = true; break;
        case SDLK_0: requested_scenario = "empty"; break;
        case SDLK_8: requested_scenario = "max_group"; break;
        case SDLK_g: requested_scenario = ui_dot_is_screen(ui_current())?"dot_idle":"group"; break;
        case SDLK_d: requested_scenario = ui_dot_is_screen(ui_current())?"dot_stale":"stale"; break;
        case SDLK_l: requested_scenario = ui_dot_is_screen(ui_current())?"dot_offline":"link_down"; break;
        case SDLK_x:
            requested_scenario = ui_dot_is_screen(ui_current())?"dot13":"rx";
            if(ui_dot_is_screen(ui_current()))requested_screen=ui_current();
            break;
        case SDLK_t: requested_scenario = ui_dot_is_screen(ui_current())?"dot_tx":"tx"; break;
        case SDLK_b: requested_scenario = ui_dot_is_screen(ui_current())?"dot_busy":"busy"; break;
        case SDLK_m: sim_action("mute",0); break;
        default: break;
    }
    return 1;
}

static void pump_window(uint32_t ms)
{
    uint32_t start = SDL_GetTicks();
    while (SDL_GetTicks() - start < ms) { lv_timer_handler(); SDL_Delay(5); }
}

static void on_display_resize(lv_event_t *event)
{
    lv_display_t *display = lv_event_get_target(event);
    /* SDL reallocates the buffer even when only zoom changes. Invalidate the
     * whole screen so unchanged controls are restored along with live labels. */
    lv_obj_invalidate(lv_display_get_screen_active(display));
}

static bool sdl_drag(uint32_t id,int zoom,int x,int y,int ex,int ey)
{
    SDL_Event e={0};e.type=SDL_MOUSEBUTTONDOWN;e.button.windowID=id;
    e.button.button=SDL_BUTTON_LEFT;e.button.state=SDL_PRESSED;e.button.x=x*zoom;e.button.y=y*zoom;
    if(SDL_PushEvent(&e)!=1)return false;pump_window(60);
    for(int i=1;i<=6;i++) {
        e=(SDL_Event){0};e.type=SDL_MOUSEMOTION;e.motion.windowID=id;e.motion.state=SDL_BUTTON_LMASK;
        e.motion.x=(x+(ex-x)*i/6)*zoom;e.motion.y=(y+(ey-y)*i/6)*zoom;
        if(SDL_PushEvent(&e)!=1)return false;pump_window(30);
    }
    e=(SDL_Event){0};e.type=SDL_MOUSEBUTTONUP;e.button.windowID=id;e.button.button=SDL_BUTTON_LEFT;
    e.button.state=SDL_RELEASED;e.button.x=ex*zoom;e.button.y=ey*zoom;
    if(SDL_PushEvent(&e)!=1)return false;pump_window(60);return true;
}

/* Check the SDL renderer as well as LVGL's memory: a correct logical PNG alone
 * cannot detect presentation problems in the desktop backend. */
static bool renderer_matches_frame(lv_display_t *display)
{
    SDL_Renderer *renderer=lv_sdl_window_get_renderer(display);
    int w,h;if(SDL_GetRendererOutputSize(renderer,&w,&h)!=0)return false;
    uint16_t *pixels=malloc((size_t)w*(size_t)h*2);if(!pixels)return false;
    bool ok=SDL_RenderReadPixels(renderer,NULL,SDL_PIXELFORMAT_RGB565,pixels,w*2)==0;
    const lv_draw_buf_t *b=lv_display_get_buf_active(display);
    if(ok)for(int y=0;y<320&&ok;y++)for(int x=0;x<240;x++) {
        uint16_t expected=((const uint16_t *)(b->data+y*b->header.stride))[x];
        int sx=(2*x+1)*w/(2*240),sy=(2*y+1)*h/(2*320);
        if(pixels[sy*w+sx]!=expected){ok=false;break;}
    }
    free(pixels);if(!ok)fputs("SDL renderer differs from LVGL logical frame\n",stderr);return ok;
}

static int test_window(lv_display_t *display)
{
    /* Exercise the real SDL driver and pixel-to-touch coordinate conversion.
     * CTest uses SDL's dummy video driver; the same test can open a real window. */
    uint32_t id = SDL_GetWindowID(lv_sdl_window_get_window(display));
    pump_window(150);
    for (int zoom = 1; zoom <= 3; zoom++) {
        uint32_t before_zoom = capture_frame_hash();
        lv_sdl_window_set_zoom(display, (float)zoom);
        pump_window(100);
        if (before_zoom != capture_frame_hash()) {
            fprintf(stderr, "Zoom %d changed the logical framebuffer\n", zoom); return 1;
        }
        if (lv_display_get_horizontal_resolution(display) != 240 ||
            lv_display_get_vertical_resolution(display) != 320) return 1;
        SDL_Event event = {0};
        event.type = SDL_MOUSEBUTTONDOWN;
        event.button.windowID = id; event.button.button = SDL_BUTTON_LEFT;
        event.button.state = SDL_PRESSED;
        event.button.x = 208 * zoom; event.button.y = 285 * zoom;
        if (SDL_PushEvent(&event) != 1) return 1;
        pump_window(100);
        event.type = SDL_MOUSEBUTTONUP; event.button.state = SDL_RELEASED;
        if (SDL_PushEvent(&event) != 1) return 1;
        pump_window(100);
        if (ui_current() != zoom % UI_SCREEN_COUNT) {
            fprintf(stderr, "SDL mouse mapping failed at zoom %d\n", zoom); return 1;
        }
    }
    SDL_Event key = {0};
    key.type = SDL_KEYDOWN; key.key.windowID = id; key.key.keysym.sym = SDLK_SPACE;
    if (SDL_PushEvent(&key) != 1) return 1;
    pump_window(80);
    if (!pause_requested || !capture_png("window.png")) return 1;
    pause_requested = false;
    SDL_Event text = {0}; text.type = SDL_TEXTINPUT; text.text.windowID = id;
    strcpy(text.text.text, " ");
    SDL_PushEvent(&text); pump_window(50);
    if (pause_requested) { fputs("Duplicate keydown/text handling\n", stderr); return 1; }
    key.type = SDL_KEYUP; SDL_PushEvent(&key); pump_window(50);
    SDL_PushEvent(&text); pump_window(50);
    if (!pause_requested) { fputs("Text-only Space did not arrive\n", stderr); return 1; }
    strcpy(text.text.text, "Z"); SDL_PushEvent(&text); pump_window(50);
    if (!zoom_cycle_requested) return 1;
    strcpy(text.text.text, "2"); SDL_PushEvent(&text); pump_window(50);
    if (requested_screen != UI_SCREEN_RADAR) return 1;
    ui_model_t dot_model;scenario_fill("dot13",0,&dot_model);
    ui_show(UI_SCREEN_DOT13);ui_update(&dot_model);pump_window(100);
    for(int z=1;z<=3;z++) {
        uint32_t before=capture_frame_hash();
        lv_sdl_window_set_zoom(display,(float)z);pump_window(100);
        if(capture_frame_hash()!=before)return 1;
        for(int i=1;i<=4;i++) {
            if(!sdl_drag(id,z,200,150,35,150)||ui_current()!=13+i%4)return 1;
        }
        for(int i=1;i<=4;i++) {
            if(!sdl_drag(id,z,35,150,200,150)||ui_current()!=13+(4-i%4)%4)return 1;
        }
        if(capture_frame_hash()!=before)return 1;
        if(!sdl_drag(id,z,120,230,120,60)||ui_current()!=UI_SCREEN_DOT13)return 1;
        char file[40];snprintf(file,sizeof(file),"dot-window-%dx.png",z);
        if(!capture_png(file))return 1;
    }
    ui_show(UI_SCREEN_DOT14);ui_update(&dot_model);pump_window(100);
    uint32_t fixed=capture_outside_wave_hash();
    for(unsigned phase=1;phase<=26;phase++) {
        dot_model.animation_ms=phase*160;ui_update(&dot_model);pump_window(35);
        if(capture_outside_wave_hash()!=fixed) {
            fputs("SDL partial refresh changed content outside waveform\n",stderr);return 1;
        }
        if(!renderer_matches_frame(display))return 1;
    }
    dot_model.peers[0].muted=true;ui_update(&dot_model);pump_window(80);
    if(!renderer_matches_frame(display))return 1;
    dot_model.voice=UI_VOICE_TX;ui_update(&dot_model);pump_window(80);
    if(!renderer_matches_frame(display))return 1;
    dot_model.link_ok=false;ui_update(&dot_model);pump_window(80);
    if(!renderer_matches_frame(display))return 1;
    puts("PASS: SDL zoom/mouse/keyboard/text input, duplicate suppression, PNG export");
    puts("PASS: Dot forward/backward swipes and vertical rejection at 1x/2x/3x");
    puts("PASS: SDL renderer readback matches RGB565 frame through waveform/mute/TX/offline updates");
    return 0;
}

static void help(void)
{
    puts("RoadWeave LVGL simulator (240x320 RGB565)\n"
         "  --scenario NAME   group radar convoy empty max_group max_convoy stale\n"
         "                    radar_east radar_far rx tx busy link_down\n"
         "  --capture FILE    Render a deterministic headless PNG, then exit\n"
         "  --reference FILE  Compare with an existing baseline (requires --capture)\n"
        "  --test-input      Run deterministic touch tests, then exit\n"
         "  --test-dot        Run dot swipe/state tests, then exit\n"
         "  --test-window     Test SDL input at all zoom levels, then exit\n"
         "  --zoom 1|2|3      Interactive zoom (default 2)\n"
         "  --paused          Start interactive mode paused\n"
         "  --seconds N       Auto-close interactive mode after N real seconds\n"
         "  --trace-input     Print SDL keyboard events for input diagnostics\n"
         "Keys: 1/2/3 legacy; 4/5/6/7 Dot 13-16; F1/F2/F3 or Z zoom; Space pause; . step; S PNG\n"
         "      Dot: swipe left = next, right = previous (wrap); M mute; R reset\n"
         "      G normal; 0 empty; 8 max peers; D stale; L link down; X RX; T TX; B busy\n"
         "Mouse: touch buttons; drag lists to scroll; Esc closes.\n"
         "PTT/mute affect simulated data only. No radio, USB or credentials are used.");
}

int main(int argc, char **argv)
{
    const char *scenario = "group", *output = NULL, *reference = NULL;
    bool inputs = false, paused = false, window_test = false, dot_inputs = false;
    int zoom = 2;
    double duration = 0;
    for (int i = 1; i < argc; i++) {
        if (!strcmp(argv[i], "--help")) { help(); return 0; }
        else if (!strcmp(argv[i], "--test-input")) inputs = true;
        else if (!strcmp(argv[i], "--test-dot")) { inputs = true; dot_inputs = true; }
        else if (!strcmp(argv[i], "--test-window")) window_test = true;
        else if (!strcmp(argv[i], "--paused")) paused = true;
        else if (!strcmp(argv[i], "--trace-input")) trace_input = true;
        else if (!strcmp(argv[i], "--scenario") && i + 1 < argc) scenario = argv[++i];
        else if (!strcmp(argv[i], "--capture") && i + 1 < argc) output = argv[++i];
        else if (!strcmp(argv[i], "--reference") && i + 1 < argc) reference = argv[++i];
        else if (!strcmp(argv[i], "--zoom") && i + 1 < argc) zoom = atoi(argv[++i]);
        else if (!strcmp(argv[i], "--seconds") && i + 1 < argc) duration = atof(argv[++i]);
        else { help(); return 2; }
    }
    if (!scenario_valid(scenario) || zoom < 1 || zoom > 3 || duration < 0 ||
        (reference && !output) || (inputs && output) || (window_test && (inputs || output))) { help(); return 2; }
    bool headless = output || inputs;
    lv_init();
    lv_display_t *display;
    if (headless) {
        display = lv_test_display_create(240, 320);
        lv_display_set_color_format(display, LV_COLOR_FORMAT_RGB565);
    } else {
        SDL_SetMainReady();
        display = lv_sdl_window_create(240, 320);
        if (!display || !lv_sdl_window_get_window(display)) {
            fprintf(stderr, "SDL window failed: %s\n", SDL_GetError());
            return 1;
        }
        lv_sdl_window_set_zoom(display, (float)zoom);
        lv_sdl_window_set_resizeable(display, false);
        lv_sdl_mouse_create();
        SDL_StartTextInput();
        main_thread = SDL_ThreadID();
        SDL_AddEventWatch(event_watch, NULL);
        help();
    }
    ui_set_action_cb(sim_action);
    ui_create(display);
    if (!headless) lv_display_add_event_cb(display, on_display_resize, LV_EVENT_RESOLUTION_CHANGED, NULL);
    ui_show(scenario_screen(scenario));
    ui_model_t model;
    scenario_fill(scenario, 0, &model);
    ui_update(&model);

    if (window_test) {
        int result = test_window(display);
        SDL_DelEventWatch(event_watch, NULL);
        lv_deinit();
        return result;
    }

    if (headless) {
        int result = 0;
        lv_test_wait(300);
        if (inputs) result = dot_inputs ? test_dot_interactions() : test_interactions();
        else {
            result = test_scenario(scenario, &model);
            if (!capture_png(output)) result = 1;
            if (reference && lv_test_screenshot_compare(reference) != LV_TEST_SCREENSHOT_RESULT_PASSED) {
                fprintf(stderr, "FAIL: %s differs from baseline or baseline is missing\n", scenario);
                capture_diff(reference, "diff.png");
                result = 1;
            }
            if (!result) printf("PASS: %s -> %s\n", scenario, output);
        }
        lv_deinit();
        return result;
    }

    uint32_t start = SDL_GetTicks(), last = start, screenshot_number = 0;
    float sim_time = 0;
    while (!quit_requested) {
        lv_timer_handler(); /* Includes SDL event polling. */
        if (quit_requested) break;
        uint32_t now = SDL_GetTicks();
        if (duration > 0 && (now - start) / 1000.0 >= duration) break;
        if (pause_requested) { paused = !paused; pause_requested = false; }
        if (!paused) sim_time += (now - last) / 1000.0f;
        last = now;
        if (step_requested) { paused = true; sim_time += 0.1f; step_requested = false; }
        if (reset_requested) { sim_time = 0; sim_reset_controls(); reset_requested = false; }
        if (requested_scenario) {
            ui_screen_t previous = ui_current();
            scenario = requested_scenario; requested_scenario = NULL;
            sim_time = 0; sim_reset_controls(); ui_show(scenario_screen(scenario));
            if (ui_dot_is_screen(previous) && strncmp(scenario,"dot_",4)==0) ui_show(previous);
        }
        if (requested_screen >= 0) { ui_show((ui_screen_t)requested_screen); requested_screen = -1; }
        if (requested_zoom) { zoom = requested_zoom; lv_sdl_window_set_zoom(display, (float)zoom); requested_zoom = 0; }
        if (zoom_cycle_requested) {
            zoom = zoom % 3 + 1; lv_sdl_window_set_zoom(display, (float)zoom); zoom_cycle_requested = false;
        }
        scenario_fill(scenario, sim_time, &model);
        sim_apply_controls(&model);
        ui_update(&model);
        char screen_name[24];
        if(ui_dot_is_screen(ui_current()))snprintf(screen_name,sizeof(screen_name),"dot%d",ui_current());
        else snprintf(screen_name,sizeof(screen_name),"%s",scenario);
        if (save_requested) {
            char filename[128];
            snprintf(filename, sizeof(filename), "capture-%s-%u-%u.png", screen_name, start, ++screenshot_number);
            if (capture_png(filename)) printf("Saved %s\n", filename);
            save_requested = false;
        }
        char title[180];
        snprintf(title, sizeof(title), "RoadWeave | %s | %.1fs %s | %dx | Space:pause S:PNG 1/2/3:screen",
                 screen_name, (double)sim_time, paused ? "PAUSED" : "RUNNING", zoom);
        lv_sdl_window_set_title(display, title);
        SDL_Delay(10);
    }
    SDL_DelEventWatch(event_watch, NULL);
    lv_deinit();
    return 0;
}

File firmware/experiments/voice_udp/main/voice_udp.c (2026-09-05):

// RoadWeave P0-B prep: end-to-end voice over UDP with the XIAO's 2.4 GHz Wi-Fi as a
// stand-in for HaLow. Same code path as the product (I2S -> ADPCM -> RWP/UDP ->
// jitter buffer -> decode -> I2S). Peer is tools/rwp_peer.py on a Mac (echo / record / send).
#include <stdio.h>
#include <string.h>
#include "freertos/FreeRTOS.h"
#include "freertos/task.h"
#include "esp_wifi.h"
#include "esp_event.h"
#include "esp_netif.h"
#include "nvs_flash.h"
#include "esp_log.h"
#include "esp_timer.h"
#include "driver/i2s_std.h"
#include "driver/gpio.h"
#include "lwip/sockets.h"
#include "rwp.h"
#include "floor.h"
#include "adpcm.h"
#include "jitter.h"
#include "opus.h"
#include "esp_heap_caps.h"
#include "sdkconfig.h"

#define FS 16000
#define BLOCK_MS 20
#define BLOCK_SAMPLES (FS * BLOCK_MS / 1000)

#ifdef CONFIG_RW_COORDINATOR
#define RW_COORDINATOR 1
#else
#define RW_COORDINATOR 0
#endif
#ifdef CONFIG_RW_GROUP_BROADCAST
#define RW_GROUP_BROADCAST 1
#else
#define RW_GROUP_BROADCAST 0
#endif
#ifdef CONFIG_RW_TX_ALWAYS
#define RW_TX_ALWAYS 1
#else
#define RW_TX_ALWAYS 0
#endif
#ifdef CONFIG_RW_PLAY_ECHO
#define RW_PLAY_ECHO 1
#else
#define RW_PLAY_ECHO 0
#endif
#ifdef CONFIG_RW_CODEC_OPUS
#define RW_CODEC RWP_CODEC_OPUS
#else
#define RW_CODEC RWP_CODEC_IMA_ADPCM
#endif

static const char *TAG = "voice_udp";
static i2s_chan_handle_t s_rx, s_tx;
static int s_sock = -1;
static struct sockaddr_in s_peer;
static jb_t s_jb;
static adpcm_state_t s_enc;
static SemaphoreHandle_t s_jb_lock;
static floor_node_t s_fn;
static floor_coord_t s_coord;
static struct sockaddr_in s_coord_addr, s_bcast;
static volatile uint32_t st_ctrl_tx = 0, st_ctrl_rx = 0, st_grants = 0, st_denies = 0, st_busy = 0, st_fail = 0;
static int16_t s_last_out[BLOCK_SAMPLES]; static int s_plc_count = 0;
static OpusEncoder *s_opus_enc; static OpusDecoder *s_opus_dec; static uint32_t s_dec_stream = 0;
static volatile int64_t st_busy_us = 0;   // audio-task processing time (excl. blocking I2S) per report window

static volatile uint32_t st_tx = 0, st_rx = 0, st_rx_bad = 0, st_echo = 0;
static volatile int64_t st_rtt_sum = 0, st_rtt_max = 0;
static volatile int64_t st_m2e_sum = 0; static volatile uint32_t st_m2e_n = 0;

static uint32_t now_ms(void) { return (uint32_t)(esp_timer_get_time() / 1000); }

static void send_control(uint8_t ctrl, uint32_t stream_id, uint32_t lease_ms, const struct sockaddr_in *to)
{
    rwp_control_t c = { .ctrl = ctrl, .stream_id = stream_id, .lease_ms = lease_ms }; uint8_t body[RWP_CONTROL_LEN];
    rwp_control_encode(body, sizeof body, &c);
    rwp_header_t h = { .version = RWP_VERSION, .type = RWP_TYPE_CONTROL, .group_id = CONFIG_RW_GROUP_ID, .sender_id = CONFIG_RW_SENDER_ID,
                       .target_type = RWP_TARGET_NODE, .target_id = 1, .stream_id = stream_id, .capture_time = now_ms() };
    uint8_t pkt[RWP_HEADER_LEN + RWP_CONTROL_LEN]; int n = rwp_encode(pkt, sizeof pkt, &h, body, sizeof body);
    if (n > 0 && sendto(s_sock, pkt, (size_t)n, 0, (const struct sockaddr *)to, sizeof *to) == n) st_ctrl_tx++;
}

static void apply_actions(uint32_t act);

// Coordinator side: handle a control/voice packet from `from` (also used for our own requests, in-process).
static void coord_handle(const rwp_header_t *h, const uint8_t *pl, const struct sockaddr_in *from)
{
    if (h->type == RWP_TYPE_VOICE) { floor_coord_renew(&s_coord, h->sender_id, h->stream_id, now_ms()); return; }
    rwp_control_t c; if (rwp_control_decode(pl, h->payload_len, &c) != RWP_OK) return;
    if (c.ctrl == RWP_CTRL_FLOOR_REQUEST) {
        floor_coord_result_t r = floor_coord_request(&s_coord, h->sender_id, c.stream_id, now_ms());
        if (h->sender_id == CONFIG_RW_SENDER_ID) {   // our own request: answer in-process
            apply_actions(floor_node_step(&s_fn, r == FLOOR_COORD_GRANT ? FLOOR_EV_GRANT : FLOOR_EV_DENY, now_ms()));
            return;
        }
        send_control(r == FLOOR_COORD_GRANT ? RWP_CTRL_FLOOR_GRANT : RWP_CTRL_FLOOR_DENY, c.stream_id, s_coord.cfg.lease_ms, from);
    } else if (c.ctrl == RWP_CTRL_FLOOR_RENEW) floor_coord_renew(&s_coord, h->sender_id, c.stream_id, now_ms());
    else if (c.ctrl == RWP_CTRL_PTT_END) floor_coord_end(&s_coord, h->sender_id, c.stream_id);
}

// Node side: perform the actions the floor FSM asked for.
static bool s_tx_running = false;
static void apply_actions(uint32_t act)
{
    if (act & FLOOR_ACT_SEND_REQUEST) {
#if RW_COORDINATOR
        rwp_control_t c = { .ctrl = RWP_CTRL_FLOOR_REQUEST, .stream_id = s_fn.stream_id }; uint8_t body[RWP_CONTROL_LEN];
        rwp_control_encode(body, sizeof body, &c);
        rwp_header_t h = { .type = RWP_TYPE_CONTROL, .sender_id = CONFIG_RW_SENDER_ID, .stream_id = s_fn.stream_id, .payload_len = RWP_CONTROL_LEN };
        coord_handle(&h, body, NULL);
#else
        send_control(RWP_CTRL_FLOOR_REQUEST, s_fn.stream_id, 0, &s_coord_addr);
#endif
    }
    if (act & FLOOR_ACT_START_TX) { s_tx_running = true; adpcm_state_init(&s_enc); st_grants++; }
    if (act & FLOOR_ACT_STOP_TX) s_tx_running = false;
    if (act & FLOOR_ACT_SEND_RENEW) {
#if RW_COORDINATOR
        floor_coord_renew(&s_coord, CONFIG_RW_SENDER_ID, s_fn.stream_id, now_ms());
#else
        send_control(RWP_CTRL_FLOOR_RENEW, s_fn.stream_id, 0, &s_coord_addr);
#endif
    }
    if (act & FLOOR_ACT_SEND_END) {
#if RW_COORDINATOR
        floor_coord_end(&s_coord, CONFIG_RW_SENDER_ID, s_fn.stream_id);
#else
        send_control(RWP_CTRL_PTT_END, s_fn.stream_id, 0, &s_coord_addr);
#endif
    }
    if (act & FLOOR_ACT_INDICATE_BUSY) st_busy++;
    if (act & FLOOR_ACT_INDICATE_FAIL) st_fail++;
}

// ---------------- Wi-Fi ----------------
static EventGroupHandle_t s_ev; enum { EV_GOT_IP = 1 };
static void wifi_evt(void *arg, esp_event_base_t base, int32_t id, void *data)
{
    if (base == WIFI_EVENT && id == WIFI_EVENT_STA_START) esp_wifi_connect();
    else if (base == WIFI_EVENT && id == WIFI_EVENT_STA_DISCONNECTED) { ESP_LOGW(TAG, "wifi disconnected, retrying"); vTaskDelay(pdMS_TO_TICKS(1000)); esp_wifi_connect(); }
    else if (base == IP_EVENT && id == IP_EVENT_STA_GOT_IP) {
        ip_event_got_ip_t *e = data; ESP_LOGI(TAG, "got ip " IPSTR, IP2STR(&e->ip_info.ip)); xEventGroupSetBits(s_ev, EV_GOT_IP);
    }
}
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

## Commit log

2026-09-01 firmware: add safe XIAO ESP32-S3 smoke test
2026-09-01 ci: build ESP32-S3 firmware with ESP-IDF 5.4.4
2026-09-05 firmware: add rwp component (RWP/0.1 wire format, floor control) with host tests and CI job
2026-09-05 firmware: add libopus component and ESP32-S3 Opus benchmark with 2026-09-05 results
2026-09-05 firmware: add audio_pipeline (IMA-ADPCM, jitter buffer) with host tests, voice_udp Wi-Fi stand-in experiment, tools/rwp_peer.py, Heltec HC01P board files and draft profile; CI host tests
    [rwp_peer.py]
2026-09-05 audio_pipeline: underrun-driven jitter growth, shrink hold-off, per-frame tags; voice_udp: windowed stats, correct mouth-to-ear; docs: 2026-09-06 voice_udp measurement (no antenna)
    [voice_udp.c]
2026-09-05 floor: BUSY_WAIT retry while PTT held (found by new host simulator); sim: 6 scenarios in CI; voice_udp: floor control, coordinator role, broadcast mode, PLC; docs: power measurement plan, 2nd voice_u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
2026-09-05 jitter: trim over-depth on re-prefill; sim: playout latency check; position component (P3 beacon/ENU/peer table) with tests; voice_udp: Opus option with native PLC and CPU meter (48 KB audio stack); 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
    [01_power_usb_battery.kicad_sch, 02_esp32s3.kicad_sch, 03_halow_hc01.kicad_sch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]
2026-09-05 ui_lvgl: LVGL 9 UI experiment (ILI9341 2.8in + XPT2046, GROUP/RADAR/CONVOY screens, simulator); KiCad skeleton validated with kicad-cli; schedule update
2026-09-05 opus_bench: 1 encoder + 2/4/6 decoders measurement
2026-09-05 docs: product definition v2 (2.8in CTP, 6-8 node groups, 2 speakers, MRF61_A), BOM v2 with 3 volume tiers, business case v2, power/GPIO/roadmap/KiCad updates
2026-09-06 Set up native Windows ESP32 benchmarks and record hardware validation
2026-09-06 Record Windows Wi-Fi Opus echo measurements on ESP32-S3
2026-09-07 docs(halow): record WM6180 SPI validation and unwired BUSY limitation
2026-09-07 docs(halow): record SPI inspection results for all three WM6180 sets
2026-09-07 feat(halow): add two-node link bench and record antenna test findings
    [partitions.csv]
2026-09-19 fix(halow): establish SPI radio links and preserve P0-A test evidence
    [board_compat.c]
2026-09-19 Tighten validation echo and metric reporting
    [validation_run.c]
2026-09-19 Avoid duplicate inclusion of Morse wrapper header
    [validation_run.c]
2026-09-19 Parse HaLow markers coalesced with driver logs
2026-09-19 Ignore prestart serial telemetry after controlled reset
    [halow_validation.py, halow_validation_run.py]
2026-09-19 Add bounded UDP throughput stage firmware
2026-09-19 Accept stage summary captured with drain acknowledgment
2026-09-19 docs: plan staged HaLow maximum performance investigation
2026-09-19 Verify full HaLow stage evidence and report observed peak
